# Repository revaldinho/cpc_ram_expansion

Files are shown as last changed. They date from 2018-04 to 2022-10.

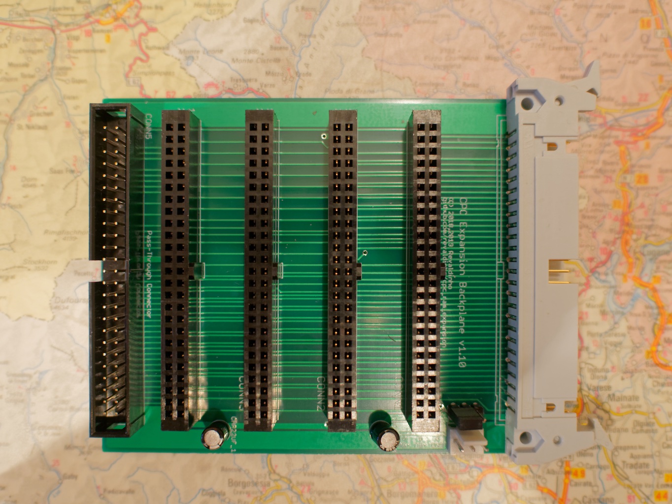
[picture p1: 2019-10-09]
img/FourSlotExpansionBoard.jpg

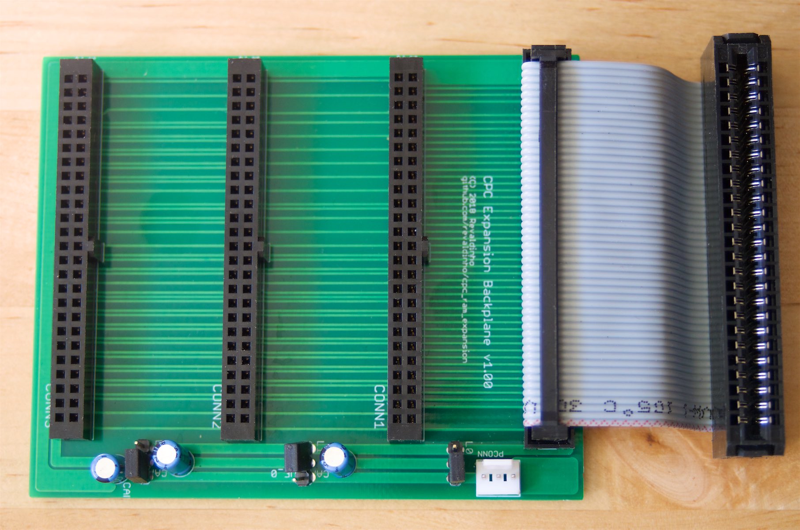
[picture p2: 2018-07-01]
img/CPC_BACKPLANE_photo.jpg

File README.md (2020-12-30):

# Amstrad CPC RAM Expansion

The main event in this GitHub project is a 1MByte RAM Expansion card for the Amstrad CPC computers from the 1980s.

In fact there are several mini-projects in here and each has its own local README file:

  * CPC RAM Expansion Cards
    * Two ['Old School'](https://github.com/revaldinho/cpc_ram_expansion/wiki/'Old-School'-CPC6128-512KB-and-1MB-RAM-Expansion-Cards) cards specifically for the 6128 and 6128 Plus and created entirely with standard 74 series ICs
      * 512KByte version
      * 1MB Version
    * [Two Universal RAM cards](https://github.com/revaldinho/cpc_ram_expansion/wiki/Universal-Amstrad-CPC-RAM-Card), compatible with all Amstrad CPC computers providing full 6128 compatibility on a 464
      * 512KByte version
      * 1MB Version
  * CPC ROM Cards
    * [CPC 4 ROM Expansion Card](https://github.com/revaldinho/cpc_ram_expansion/wiki/CPC-Fourrom-Card )
    * [CPC 6 ROM Expansion Card](https://github.com/revaldinho/cpc_ram_expansion/wiki/CPC-Sixrom-Card )
    * [CPC 8 ROM Expansion Card](https://github.com/revaldinho/cpc_ram_expansion/wiki/CPC-Eightrom-Card )
  * [CPC Expansion backplanes](https://github.com/revaldinho/cpc_ram_expansion/wiki/CPC-Expansion-Backplane)
    * 3 slot basic backplane
    * 4 slot with box connector feedthrough
    * 4 slot with replicated edge connector, allowing legacy peripherals to be daisy chained

All of the above projects have been built and tested.

Eagle PCB files and zipped archives suitable for getting boards made are included in the  [Eagle Releases](https://github.com/revaldinho/cpc_ram_expansion/blob/master/eagle_releases) subdirectory.
    
For more information on all projects see the [Project Wiki Pages](http://www.github.com/revaldinho/cpc_ram_expansion/wiki)

All programs and data files in this project are made available under the terms of the [GNU General Public License v3](https://github.com/revaldinho/cpc_ram_expansion/blob/master/LICENSE).

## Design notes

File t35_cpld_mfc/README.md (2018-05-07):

```                                 A   B
 +-------------------+              +---+
 |  PC[7:0]/DOUT[7:0]|==============|245|==**====================== Data[7:0]
 |                   |           +--|oe |  ||
 |                   |           |+-|dir|  ||
 |                   |           || +---+  ||
 | PD[15:12]/DIN[3:0]|===========||========**
 |  PB[23:16]/A[15:0]|===========||========||======*=============== A[15:8]
 |     PD[7:0]/A[7:0]|===========||========||======*=============== A[7:0]
 |                   |           || 2      ||8     | 3
 |                   |    +---------------------------------+
 |                   |    |   oeb dir    D[7:0]  A[15,14,13]|
 |        PB[0]/gpio0|-**-| gpio0[romselwr]            mreqb|------ MREQB
 |        PB[1]/gpio1|-**-| gpio1[hiromrd]            ioreqb|------ IOREQB
 |        PB[2]/gpio2|-**-| gpio2[loromrd]               wrb|------ WRB
 |        PB[3]/gpio3|-**-| gpio3                        rdb|------ RDB
 |        PB[4]/gpio4|-**-| gpio4                      romen|------ ROMEN
 |        PB[5]/gpio5|-**-| gpio5                     romdis|--|>|- ROMDIS
 |        PC[8]/gpio6|-**-| gpio6[romvalid]            waitb|------ READY
 |        PC[9]/gpio7|-**-| gpio7                        clk|------ CLK
 |                   | || |                           resetb|------ RESETB 
 |                   | || |                              m1b|------ M1B   
 |                   | || |                           busreq|------ BUSREQ
 |                   | || |                           busack|------ BUSACK
 |                   | || |                             intb|------ INT   
 |                   | || |                                 |13
 |                   | || |                             JTAG|====== JTAG TDO/TMS/TDI/TCK
 |                   | || +---------------------------------+ 4
 |       PC[10]/gpio8| || 8          
 |       PC[11]/gpio9| ++========================================== Box conn 2: 10W 
 |      PB[10]/gpio10|    
 |      PB[11]/gpio11|                                             
 |       PD[8]/gpio12|============================================= Box conn 2: 10W 
 |       PD[9]/gpio13|         
 |      PE[10]/gpio14|                                             
 |      PE[11]/gpio15|                                             
 |                   |                                         
 |      PE[24]/gpio16|                                         
 |      PE[25]/gpio17|============================================= Conn 3: 4 pin I2C 
 |                   |                                      ___
 |              DAC0 |--o pin                             o|o_o|  L1 [5V_CPC vs 5V_EXT] 
 |              DAC1 |--o pin                             _____
 +-------------------+                                    o-o o  CONN0 5V_EXT     

Questions
---------

T35 RESET access ? Separate on off (use ext supply/link) ?

Notes
-----

- USB/VIN connection needs cutting on T35 to allow use with CPC 5V in
- 3V3 supply for 9572XL parts?
  o could be second link to use T25 3V3 output [250mA]?
  o need a second link for VDD_Core pins + separate decap          
- can remove '245 and short A-B if T35 can turnaround bus quickly enough

PMOD Specs
----------

https://www.digilentinc.com/Pmods/Digilent-Pmod_%20Interface_Specification.pdf

Also check BlackIce pin out

CPLD Notes

User IO Available = 34
CPLD Tot = 8 + 2 + 8 + 3 + 13 = 34

T35 Notes

Ports Available

B[5:0], [11,10], [23:16]
C[11:0]
D[9:0], [15:11]
E[10,11,24,25,26]

SW Notes
--------

CPLD can create easier conditions to deal with e.g.

ROMSEL_WR - !A13 & !IOREQB & !WRB

HIROM_RD  - !ROMENB & A14 & ROMVALID

LOROM_RD  - !ROMENB & !A14

CPLD output signals 

ROMDIS    - !ROMENB & (ROMVALID + !A14)

OEB       - !ROMDIS

DIR       - 1'b0 - always B->A T34-> CPC in this application

Init
   ROMVALID = 0
   Tristate DOUT

On ROMSEL
   sample DATA
   save into ROMSEL
   set ROMVALID
   while ROMSEL {}

On HIROM_RD
   sample ADRHI
   sample ADRLO
   DOUT = rom[ROMSEL][ADR&0x3FFF]
   while HIROM_RD{}
   Tristate DOUT

On LOROM_RD
   sample ADRHI
   sample ADRLO
   DOUT = lorom[ADR&0x3FFF]
   while LOROM_RD{}
   Tristate DOUT
```

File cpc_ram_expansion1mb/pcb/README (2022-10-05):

#!/bin/tcsh -f
# Need to have access to the Jython netlister program
set netlister_dir = ../../../netlister
which netlister.py > /dev/null
if ($status != 0) then
   setenv CLASSPATH ${netlister_dir}/src:$CLASSPATH
   setenv PATH      ${netlister_dir}/src:$PATH
   rehash
endif

setenv TERM xterm

cp ../../common_pcb/autorouter.ctl /tmp
cp ../../common_pcb/autorouter_74.ctl /tmp
cp ../../common_pcb/design_rules.dru /tmp

## Revised CPLD based RAM board - 464 and 6128
make cpc_ram1m_plcc84.net -f ../../common_pcb/Makefile
make cpc_ram1m_plcc84.scr -f ../../common_pcb/Makefile
make cpc_ram1m_74_v2.00.net -f ../../common_pcb/Makefile
make cpc_ram1m_74_v2.00.scr -f ../../common_pcb/Makefile

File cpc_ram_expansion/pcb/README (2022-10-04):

#!/bin/tcsh -f

# Need to have access to the Jython netlister program
set netlister_dir = ~/iCloudDrive/Development/git/netlister
which netlister.py > /dev/null
if ($status != 0) then
   setenv CLASSPATH ${netlister_dir}/src:$CLASSPATH
   setenv PATH      ${netlister_dir}/src:$PATH
   rehash
endif

setenv TERM xterm

cp ../../common_pcb/design_rules.dru /tmp
cp ../../common_pcb/autorouter.ctl /tmp

## ## Original CPLD based RAM board - 6128 only
## make cpc_ram_board.net -f ../../common_pcb/Makefile
## make cpc_ram_board.scr -f ../../common_pcb/Makefile

## Revised CPLD based RAM board - 464 and 6128
make cpc_ram512k_v110.net -f ../../common_pcb/Makefile
make cpc_ram512k_v110.scr -f ../../common_pcb/Makefile

cp ../../common_pcb/design_rules.dru /tmp
cp ../../common_pcb/autorouter_74.ctl /tmp

#make cpc_ram_board_74_v2.01.scr ARGS='"-D ALT_POWER=1"' -f ../../common_pcb/Makefile
#make cpc_ram_board_74_v2.01.net ARGS='"-D ALT_POWER=1"' -f ../../common_pcb/Makefile

make cpc_ram_board_74_v3.00.scr -f ../../common_pcb/Makefile
make cpc_ram_board_74_v3.00.net -f ../../common_pcb/Makefile

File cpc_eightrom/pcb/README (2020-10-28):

#!/bin/tcsh -f

# Need to have access to the Jython netlister program

set netlister_dir = ~/Documents/nas/Development/git/netlister
which netlister.py > /dev/null
if ($status != 0) then
   setenv CLASSPATH ${netlister_dir}/src:$CLASSPATH
   setenv PATH      ${netlister_dir}/src:$PATH
   rehash
endif

setenv TERM xterm

cp ../../common_pcb/autorouter.ctl /tmp
cp ../../common_pcb/autorouter_74.ctl /tmp
cp design_rules.dru /tmp

## Revised CPLD based RAM board - 464 and 6128
make cpc_eightrom.net -f ../../common_pcb/Makefile
make cpc_eightrom.scr -f ../../common_pcb/Makefile

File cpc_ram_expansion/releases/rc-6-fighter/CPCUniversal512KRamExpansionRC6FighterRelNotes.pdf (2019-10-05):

## Summary

This is 512KByte memory expansion card which is suitable for all Amstrad CPC computers.

The card has an MX4 type connector, so requires an expansion board [1] or suitable ribbon cable connection to hook up to the computer.

On the CPC6128 and later computers the board provides a full 512K RAM expansion following the DK'Tronics/Amstrad specification.

Adding RAM to the older CPC464/664 computers is generally much more problematic than with the later models. Many of the card features are specific to these machines.

Like other RAM cards, it provides full DK'Tronics compatibility when used with the CPC464 and CPC664. This is sufficient to run the vast majority of software requiring additional RAM including CP/M Plus, demos such as Phortem and Batman Forever and many games.

The card also provides a unique 'shadow mode' which enables perfect Amstrad CPC6128 video mode C3 operation on CPC464/664 computers[2]. In shadow mode these older machines can now run FutureOS and other software relying on this video mode and which previously would run only on CPC6128s and later machines. Shadow mode can also enable a 464 to run entirely from the card RAM without using base RAM other than for the video display. This may be useful for reviving or at least diagnosing CPC464s with faulty internal RAM.

RAM Card features are controlled DIP switches which, used in combination, provide the following controls:

Overdrive ON or OFF
- select 464/664 mode (ON) or 6128/Plus mode (OFF)

•

Shadow Mode ON or OFF [464 mode only]
- ON provides 'perfect' C3 mode/ OFF provides DK'Tronics C3 mode
NB Shadow mode requires 64KB of RAM, reducing the effective capacity of the card to 448KB

○

•

Full or Partial Shadow mode [464 mode only]
Partial shadow mode uses shadow memory only for reads from remapped RAM area in mode C3

○

•

# CPC Universal 512K Ram Expansion RC-6-Fighter Release Notes

Saturday, 5 October 2019 14:17

Full shadow mode services all CPU base RAM reads from expansion card RAM
- Base RAM still used for video output via the CRTC

○

Full shadow may be useful for reviving '464s with faulty base RAM or at least diagnosing related problems but partial shadow is the default.

○

## Compatibility

The following table sets out the basic RAM card configurations required and compatibility achieved with different CPC motherboards.

| Standard Setting | | Overdrive Setting | | Overdrive/Shadow Setting
Computer | Expansion | C3 Mode | Expansion | C3 Mode | Expansion | C3 Mode
CPC464 | NA | NA | 512K | DK'T | 448K | Amstrad
CPC664 | NA | NA | 512K | DK'T | 448K | Amstrad
CPC464 [ASIC] | 512K | DK'T | NA | NA | NA | NA
CPC464 Plus | 512K | DK'T/Amstrad | NA | NA | NA | NA
CPC6128 Plus | 512K | Amstrad | NA | NA | NA | NA
KC Compact | NA | NA | 512K | DK'T | NA | NA

RAM expansion modes C0-C2 and C4-C7 work identically across all supported machines. Only the special C3 mode (requiring remapping of base memory) behaviour differs from one model to another.

On all machines the card will provide a 512KB expansion with either DK'Tronics or Amstrad C3 mode operation.

Perfect Amstrad C3 mode operation is available on all machines other than the very late CPC464 costdown revision (ASIC in place of earlier gate arrays) and the KC Compact. These machines will still get a 512KByte expansion but are limited to the DK'Tronics type C3 mode.

By default a CPC464 Plus will also get a DK'Tronics C3 mode unless a resistor is added to the motherboard. The CPC464 Plus and CPC6128Plus motherboards are identical and this resistor is an factory option component which distinguishes between the two. It is included in the CPC6128 Plus but omitted from the CPC464 Plus builds and is needed to configure the ASIC for the additional RAM banks and enable the C3 mode RAM remapping.

When using the CPC464/664 in shadow mode the effective capacity of the card is reduced by 64K to accommodate shadowing of base memory.

## DIP Switch Settings

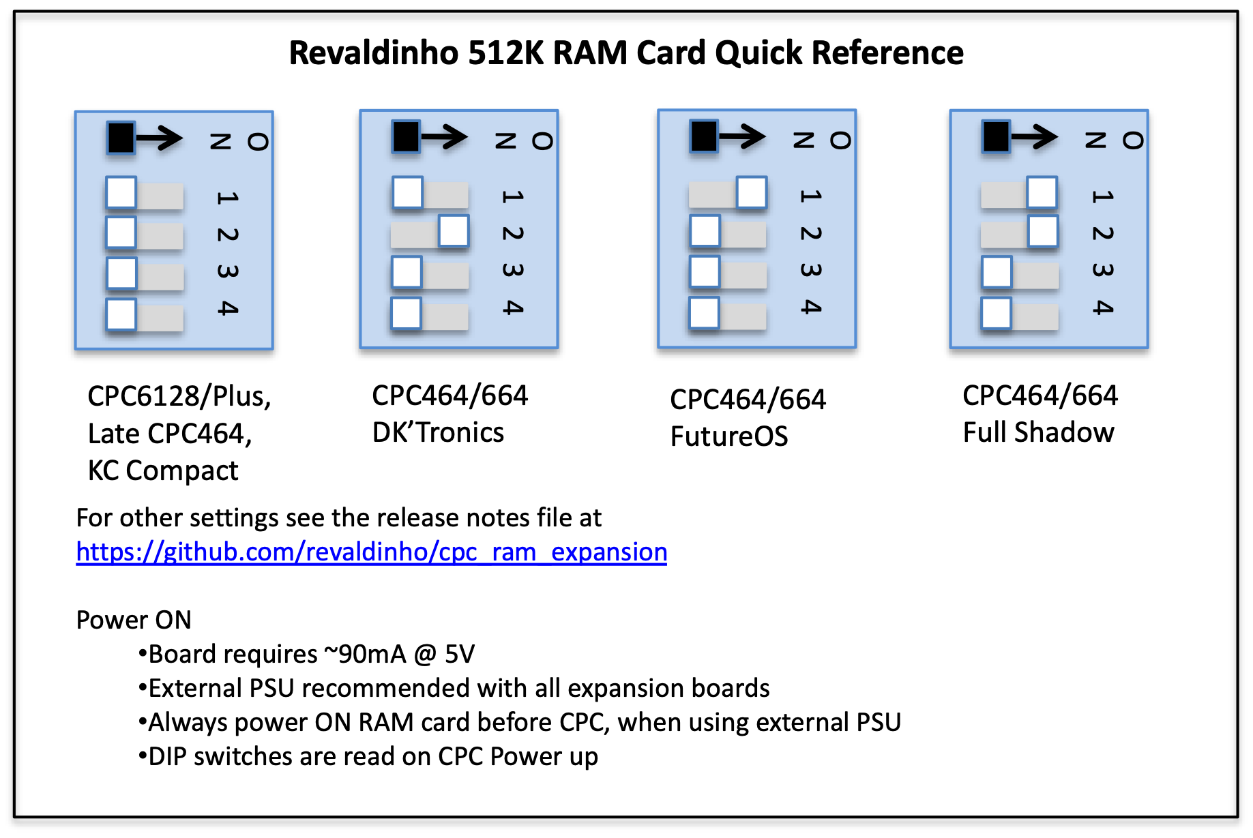
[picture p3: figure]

The new DIP settings and effects are listed below:

Config | DIP 1234 | 464/Z80 overdrive | Port | Shadow/Ban k | RAM | C3 Mode
0 | 0000 | OFF | 7Fxx | None/x | 512KB | AMSTRAD 6128
4 | 0100 | ON | 7Fxx | None/x | 512KB | DK'Tronics
8 | 1000 | ON | 7Fxx | Partial/lo | 448KB | AMSTRAD 6128
12 | 1100 | ON | 7Fxx | Full/lo | 448KB | AMSTRAD 6128

NB DIP switches 3 and 4 are not used with this firmware.

Recommended (and tested) configurations for the RAM card on its own are shown in bold in the table. E.g.

- 0 for CPC6128 providing standard 512KB expansion
- 4 for CPC464 providing 512KB expansion with DK'Tronics C3 mode
- 8 for CPC464 providing 448KB expansion with Amstrad C3 mode

Specification of other configurations is untested and may be changed in any future revisions.

## Release Notes

RC-6-Fighter is the latest firmware for the RAM card.

This release is based on RC-5-Elephant and improves low voltage operation of the card in all modes. Cards have been tested with several CPC running FutureOS and various RAM Tests and demos (including Batman and Phortem) down to around 4.1V. This should make the cards much more tolerant of poor CPC supplies and remove any need for additional external power supplies.

Unlike RC-5, the lower DIP switches are no longer used - this is because the revised logic already fills up the CPLD chip. So, the card Is now always mapped to the usual IO port &7Fxx, and doesn't have an option to relocate to &7Exx as did RC-5.

In shadow mode, the shadow bank is fixed at number 3, where previously RC-5 gave a choice of 3 or 7. Number 3 was chosen for compatibility with the DK'Tronics silicon disk software. This does an imperfect check for expansion RAM and fails to spot that the shadow bank is duplicating base RAM. So, it's not possible to use the silicon disk software with the bank set at 7 and hence the number 3 is chosen instead. The Dk'Tronics Bank manager software does correctly test for available memory and is able to find 192K (out of the maximum 256K it looks for) in banks 0,1 and 2.

## Footnotes

[1] Compatible expansion boards include ToTO's Mother X3, Revaldinho CPC Backplane, LambdaMikel LambdaBoard.
[2] When using shadow mode the card size is effectively reduced to 448KBytes
[3] Shadow mode cannot presently be used when deplying pairs of RAM cards or in conjunction with other RAM cards.
[4] The Batman Forever demo does not run on CTRC Type 2 machines

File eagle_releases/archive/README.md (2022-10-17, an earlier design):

# Eagle Releases Archive

DO NOT USE any releases in the archive area for new board builds.

All files in this area are outdated designs which have been replaced
by updated versions.

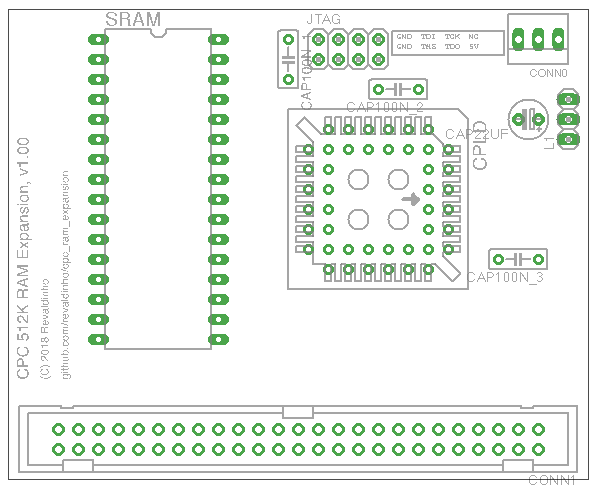
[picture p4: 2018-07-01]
img/CPC_512K_RAM_place.png

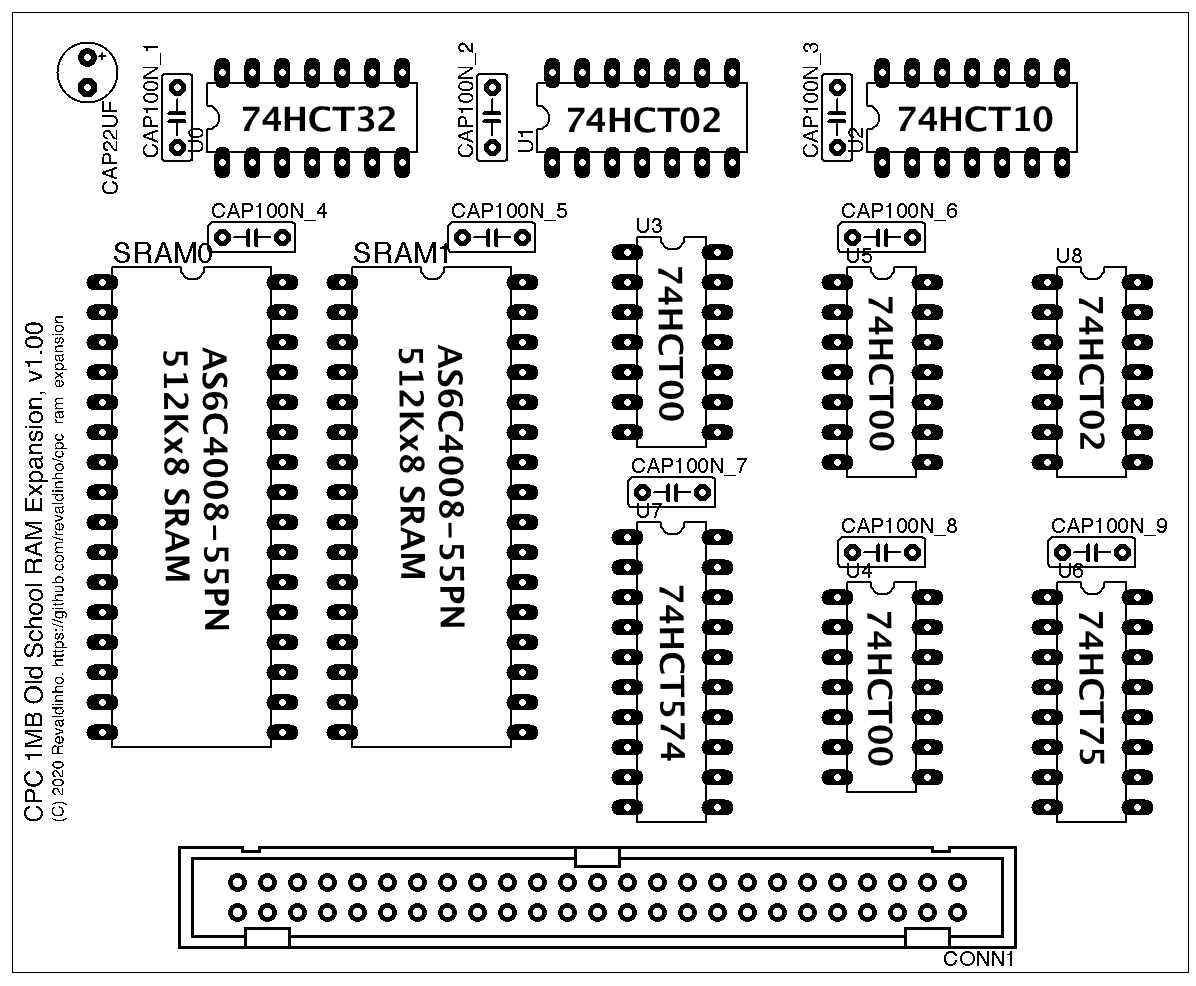
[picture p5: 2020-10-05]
img/CPC_1MB_RAM_SN74_placement_v1.00.png

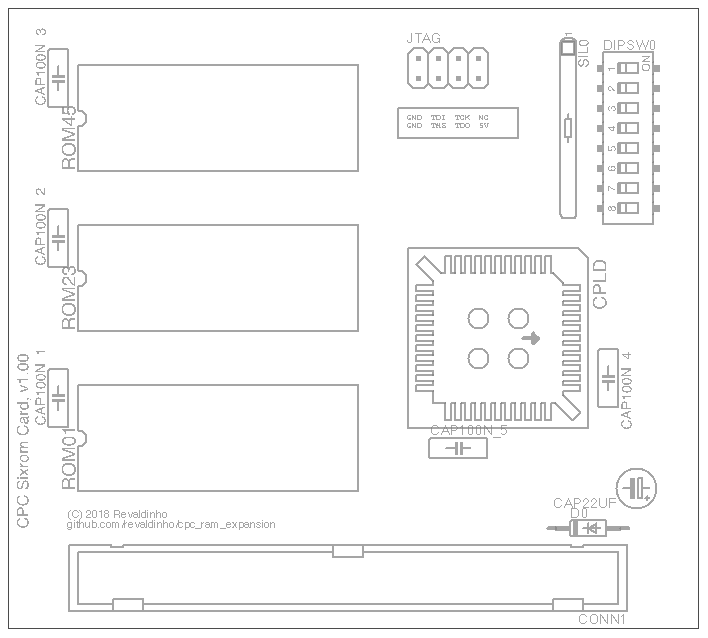
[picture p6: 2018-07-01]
img/CPC_SIXROM_place.png

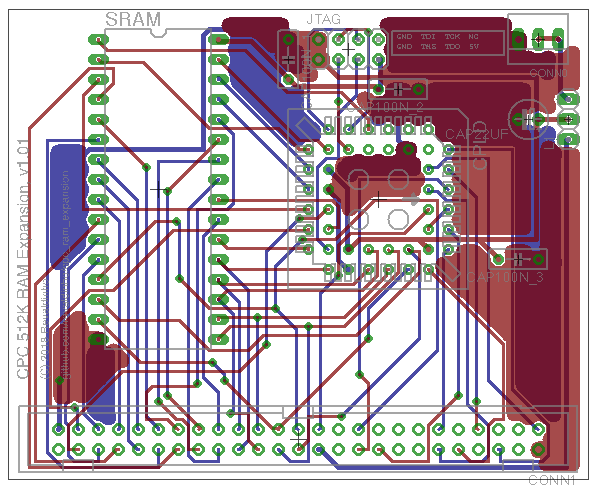
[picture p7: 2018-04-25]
img/CPC_512K_RAM_Eagle_top_v1.01.png

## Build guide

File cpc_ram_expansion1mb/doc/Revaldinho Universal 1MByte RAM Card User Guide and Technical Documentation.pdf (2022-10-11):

# Revaldinho Universal 1MByte RAM Card

# User Guide and Technical Manual

## Summary

This is a 1MByte memory expansion card which is suitable for all Amstrad CPC computers.

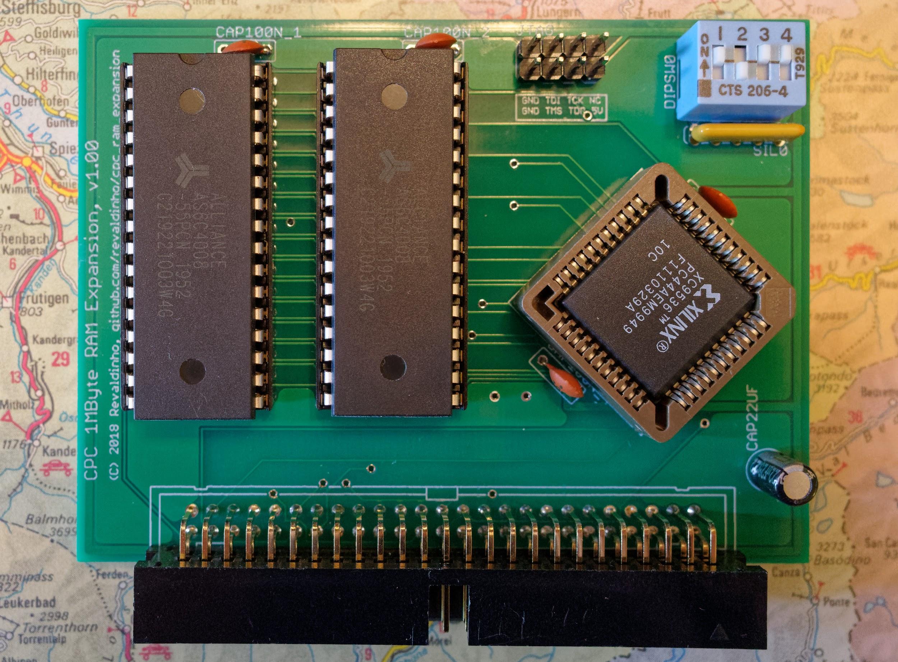
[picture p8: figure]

On all CPCs the board provides three expansion configurations
- 64KByte mode (for 464/664), to provide maximum compatibility with the CPC6128
- 512KByte mode, using Dk'Tronics expansion scheme
- 1MB mode, using the RAM7/Yarek addressing scheme.

Like other RAM cards, it provides full DK'Tronics compatibility when used with the CPC464 and CPC664 and this is sufficient to run the vast majority of software which can use the additional RAM, including CP/M Plus, demos such as Phortem and Batman Forever and many games.

The card also provides a unique 'shadow mode' which enables perfect Amstrad CPC6128 video mode C3 operation on CPC 464/664 computers. These older machines can now run FutureOS and other software which previously would run only on CPC6128s and later machines. In shadow mode the maximum expansion provided by the card is reduced to 960KBytes, as one 64KByte bank is needed to shadow the base RAM.

Shadow mode can also enable a 464 to run entirely from the card RAM without using base RAM other than for the video display. This may be useful for reviving or at least diagnosing CPC464s with faulty internal RAM.

## Table of Contents

Summary | 1
Table of Contents | 2
User Guide | 3
Installing the Card | 3
Recommended Configurations | 4
DIP Switch Settings | 4
Setting the Card Mode | 4
Setting the RAM Configuration | 6
Compatibility Tips | 7
CPC 464/664 Computers | 7
CPC 464 Plus Computers | 7
Technical Manual | 8
DK’Tronics Mode Operation | 8
Implementation and Extension of DK’Tronics Mode in the Universal Card | 10
Reduced Expansion RAM Addressing - maximum 6128 compatibility configuration. | 10
Expanded RAM Addressing - the RAM7/Yarek Scheme | 11
Shadow Mode Operation | 11
Full Shadow and Partial Shadow Modes | 12
Test Suite | 13
Validated Configurations | 14
Power Requirements | 14
Card Connector Pin-Out | 14
Downloads | 15
Additional Resources | 15
License | 15

## User Guide

### Installing the Card

The card is supplied with an MX4 type connector rather than an edge connector, so requires an expansion board or ribbon cable connection to hook up to the computer. All modern expansion boards have the same pin-out which mimics IDC connectors on a ribbon cable. The RAM card connector is keyed, to ensure that it will fit only in the correct orientation in a matching socket, such as the ones installed in the Revaldinho CPC Expansion Boards. Some other expansion boards use cheaper non-keyed connections which make it possible to insert the card the wrong way round. For those boards, take care to insert the card so that the component side of the board (including the DIP switch) is facing the rear of the Amstrad CPC computer.

The card draws approximately 100mA of current when running with a 5V supply. This should be handled by a standard CPC power supply and although cards are tested down to 4.5V to allow for some voltage drop over old edge connectors, it’s a good idea to clean the connectors on your CPC to minimize this. If your expansion board allows an external power supply to be used, then it’s recommended to connect one, particularly if you are using a number of different peripherals as well as the RAM card.

Once the card is physically installed, it’s necessary to configure it appropriately before switching on the computer. This is done by setting the 4 DIP switches on the top level of the circuit board.

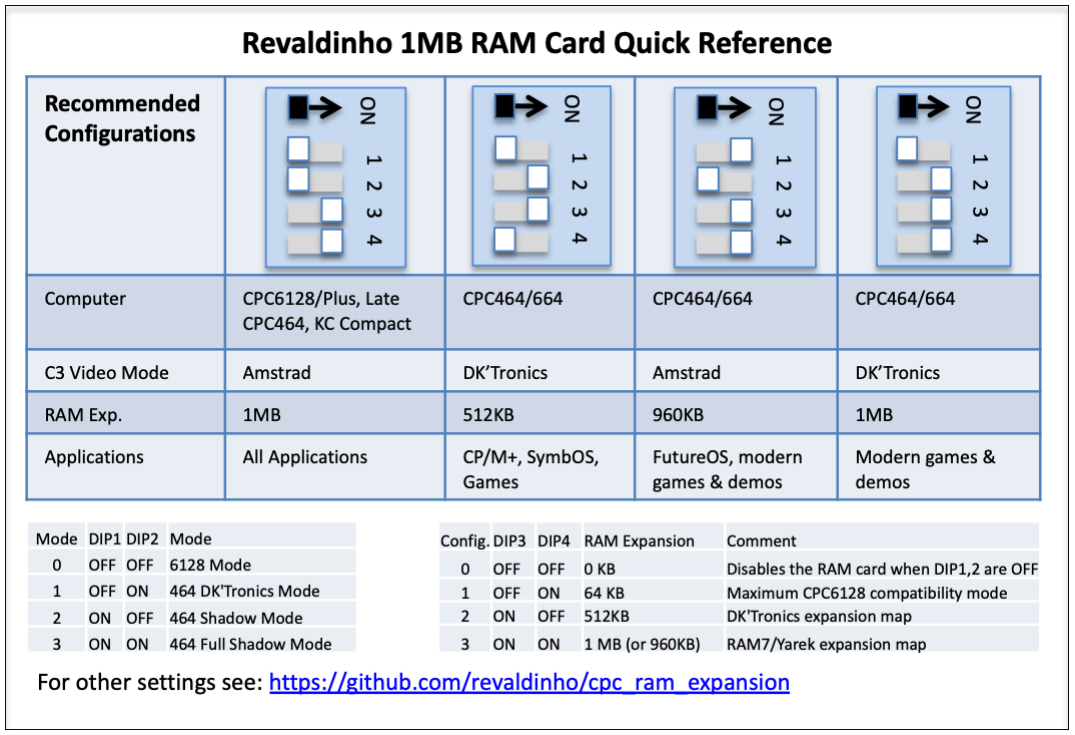
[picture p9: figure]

### Recommended Configurations

Computer | DIP1 | DIP2 | DIP3 | DIP4 | Expansion | Application
CPC 6128/Plus | OFF | OFF | ON | ON | 1MB | All
CPC 464/664 | ON | OFF | ON | ON | 960KB | FutureOS
CPC 464/664 | OFF | ON | OFF | ON | 64KB | CPC 6128 games 1
CPC 464/664 | OFF | ON | ON | OFF | 512KB | CP/M+ , SymbOS, DK’Tronics silicon disk 2
CPC 464/664 | OFF | ON | ON | ON | 1MB | Modern games & demos
All | OFF | OFF | OFF | OFF | None | Disable the card

The table above shows the most common DIP settings needed for different CPC models and software. Other settings are possible and described in more detail below.

### DIP Switch Settings

The board has four DIP switches which are grouped into two pairs
- DIP1 and DIP2 determine the card mode
- DIP3 and DIP4 determine the RAM expansion size

Changing DIP settings while the computer is running is likely to cause a crash, but even if it doesn't you should always reset the computer after a change.

### Setting the Card Mode

The card has 4 operating modes shown in the table below.

Mode | DIP1 | DIP2 | Mode | C3 Video | Comment
0 | OFF | OFF | 6128 Mode | Amstrad | Always use this mode for CPC6128 & Plus computers 3
1 | OFF | ON | DK'Tronics Mode | DK'Tronics | Basic DK'Tronics compatible expansion for CPC464/664
2 | ON | OFF | Shadow Mode | Amstrad | Enhanced mode expansion with perfect Amstrad C3
3 | ON | ON | Full Shadow Mode | Amstrad | Enhanced mode expansion with perfect Amstrad C3

For CPC 6128, CPC Plus and late ‘cost reduced’ CPC 464

3 models, always select mode 0.

The other modes are all intended for the vast majority of older CPC 464 and 664 computers. These computers do not handle expanded memory as cleanly as the CPC 6128, so the RAM card needs to overdrive some of the key CPU signals at critical moments to write-protect the CPC’s internal memory and

3 Use this mode also for very late model CPC 464 computers which have the very small motherboard and ASIC in place of the original gate array ICs.

2 See Compatibility Tips for CPC 464/664 Computers

1 May also require the CPC 6128 upper BASIC and lower Firmware ROMs to be installed.

to remap some of that memory in one specific configuration. Modes 1-3 are the only modes suitable for CPC 464/664 computers, and all implement the electrical overdrive operation.

The main difference between modes 1-3 is the way in which the C3 video mode is handled. There is a choice between DK'Tronics handling of the C3 video mode and true CPC 6128-type handling. Most software is perfectly happy with the DK'Tronics implementation. Mode 1 implements this and is good for running CP/M+ using the DK'Tronics software to provide a 256KByte RAM disk for example.

Some software needs a perfect implementation of the Amstrad C3 mode and FutureOS is perhaps the best example of this. To be able to run this software chose either mode 2 or mode 3. There is no obvious difference to the user between these two modes. In both modes 2 and 3 all CPU writes to base memory are also sent to the shadow bank in the expansion board. Mode 3 disables all CPU reads from base RAM and replaces them with read data from the expansion board, whereas mode 2 does this only for reads from the upper 16KB of base memory. Both schemes provide the perfect C3 mode operation.

Since mode 3 replaces all CPU reads from base RAM with data from the expansion board, it’s possible that using this mode could revive a CPC 464/664 with faulty base RAM. If the faulty RAM is in the video address space, then unfortunately there will still be a corrupted screen display because it’s not possible for the expansion board to service reads to the CRTC chip. Even so, in theory at least, it would be possible to boot and run a CPC 464/664 in this way which might at least help with fault diagnosis.

### Setting the RAM Configuration

As well as the operating modes, there are four possible RAM configurations described in the table below.

Config. | DIP3 | DIP4 | RAM Expansion | Comment
0 | OFF | OFF | 0 KB | Effectively disables the RAM card
1 | OFF | ON | 64 KB | Maximum CPC6128 compatibility mode
2 | ON | OFF | 512KB | DK'Tronics expansion
3 | ON | ON | 1 MB (or 960KB) | RAM7/Yarek expansion

In configuration 0, the RAM card is completely disabled. There may be rare cases where a CPC 464/664 needs to run in an unexpanded RAM mode, but you shouldn’t normally need to select this mode.

Configuration 1 is provided to give CPC 464/664s maximum compatibility with the CPC 6128. In this mode all expanded memory accesses are mapped to the same 64KByte expansion bank. This configuration can be used with both DK’Tronics and Amstrad C3 video modes (above) with no effect on the size of the expansion.

Configuration 2 models a ‘standard’ DK’Tronics 512KByte expansion scheme. DK’Tronics sold several different expansion cards back in the 80s including a 64KByte RAM expansion, a 256KByte expansion and a 256KByte silicon disk. All of these conformed to this scheme and the RAM expansion and silicon disk could be used together for a total of 512KBytes. In configuration 2, the card replicates this scheme exactly and the original DK’Tronics RAM expansion (bank management) and silicon disk software work without modification. This configuration can be used in conjunction with both DK’Tronics and Amstrad C3 video modes without affecting the size of expansion RAM available.

Configuration 3 provides the maximum memory expansion. This uses the RAM7/Yarek scheme which extends the DK’Tronics standard. Most legacy software able to access expanded RAM will be able to run in this mode even if it doesn’t access the full 1MByte. Only more modern software will make full use of this mode, but that does include the operating system FutureOS as well as a number of demos. On a CPC 464/664, FutureOS will need one of the two shadow modes 2 or 3 to be selected in conjunction with this configuration because it specifically needs the full Amstrad C3 video operation; other software will be ok with any of modes 1-3. When one of the shadow modes is selected, the maximum RAM expansion available in this configuration is reduced to 960KBytes because one 64K bank is needed to shadow the CPC’s base memory.

Note that in all cases the total RAM of the CPC is the internal 64K base memory + the additional RAM Expansion. So in 512KB mode for example, the CPC actually has 576KBytes of RAM. This is true for all machines including the CPC 6128 and Plus because the built-in 64KByte expansion in these machines is disabled when an additional RAM card is added.

### Compatibility Tips

CPC 464/664 Computers

To upgrade a CPC 464/664 computer to full CPC 6128 specification you will need to add a memory expansion card but also change both the BASIC and lower Firmware ROMs. Some games check for the ROM types to determine the machine type or RAM size for example.

Even with the CPC 6128 ROMs installed, you may find some software won’t run due to other subtle hardware differences including the keyboard scanning arrangement. DK’Tronics recognized this and provided a set of RSXes as a workaround as part of their RAM expansion software. In particular the |EMULATE command deals with differences in the keyboard map. On some CPC 464s you must install and run the RSX before you can boot into CP/M+ for example (otherwise it returns a message to the effect “CP/M+ does not support this environment”).

For most legacy CPC software, running in DK’Tronics compatibility mode (mode 1) and either 512K or 64K RAM configurations is recommended because older software wasn’t written to target the Yarek/RAM7 addressing scheme.

Note that although SymbOS claims to be Yarek/RAM7 compatible, it only recognizes 512KB of expansion on the 1MB card irrespective of whether the 512KB or 1MB memory setting is selected. Other more recent software is likely to be able to use the full 1MByte mode.

See the compatibility and testing table later for more specific software information.

CPC Plus Computers

When CPC464 and CPC6128 Plus computers are running software which makes use of advanced features new to these machines compared with the older CPC family, there are some restrictions on compatibility. Specifically, any software which remaps the ASIC register bank into RAM space (at 0x4000-0x7FFF0 must first disable the expansion RAM before performing the remapping. With the ASIC registers mapped in this space there is a clash with the expansion RAM if this is not done - all writes go to both ASIC and expansion memory; all reads come from ASIC and expansion RAM too, causing a clash on the databus.

CPC 464 Plus Computers

The CPC 464 Plus and CPC 6128 Plus share the same ASIC and motherboard, but there are differences in components fitted to the two boards. Obviously the CPC464 Plus is missing the additional 64KByte RAM bank of the CPC 6128 Plus, but less obviously this affects the way in which expansion RAM is handled in the video mode C3.

The CPC 464 Plus should always use the RAM card mode 0 (non-overdrive mode) but by default the C3 video mode will behave as it would on an older CPC 464 with a DK’Tronics expansion. However, it is possible to update the CPC 464 Plus to inherit the same clean RAM expansion handling as the CPC 6128 and by adding a single component. On page 18 of the Service Manual , “Gate Array / Output Interface

4

4 The Amstrad CPC Plus Service Manual can be found here: http://www.cpcwiki.eu/manuals/Service%20Manual%20Amstrad%20Plus.zip

Schematic Diagram” you will see a note at the bottom of the page to the effect that resistor R128 (10Kohm) needs to be added for the board to recognize an on-board 64K expansion (ie 128K rather than 64K). Adding this resistor will also update the RAM handling to that of the CPC 6128, and the 1MByte RAM card will do the rest. In this way the CPC 464 Plus can gain the full 1MB expansion and run FutureOS and other C3 mode dependent software.

## Technical Manual

The following sections describe in more detail the various RAM expansion schemes and how the card implements different compatibility modes.

### DK’Tronics Mode Operation

The board is fully compatible with the DK'Tronics/Amstrad bank switching schemes described in the DK'Tronics Peripheral Technical Manual. (http://www.cpcwiki.eu/imgs/8/83/DK%27Tronics_Peripheral_-_Technical_Manual_%28Edition_1%29.pdf)

In this scheme there are 8 possible 64K banks, and each bank is split into 4 16K blocks.
Selecting a 64K bank is done by writing to the Z80 IO address 0x7Fxx with an 8 bit dataword.
Bit position | 7 | 6 | 5 | 4 | 3 | 2 | 1 | 0
Value | 0 | 1 | c | c | c | b | b | b

The two MSBs of the byte must be set to 01 and then the rest of the byte is divided into two 3 bit fields:
- ccc - picks one of 8 possible 64K banks
- bbb - selects a block switching scheme within the chosen bank

In true DK’Tronics mode operation, the maximum RAM expansion size is limited to 512KBytes.

Within any one 64KByte bank, RAM is divided up into 4 16KByte blocks numbered from 0 (the lowest 16KBytes) to 3 (the highest 16KBytes).

The bank switching schemes for the 6128 and Plus machines are illustrated in the table below, where
- '-' indicates access to internal RAM
- 0-3 indicate access to the relevant block in the selected external expansion bank

| Block Scheme (bbb)
Address | 000 | 001 | 010 | 011 | 100 | 101 | 110 | 011
0xC000-0xFFFF | - | 3 | 3 | 3 | - | - | - | -
0x8000-0xBFFF | - | - | 2 | - | - | - | - | -
0x4000-0x7FFF | - | - | 1 | ** | 0 | 1 | 2 | 3
0x0000-0x3FFF | - | - | 0 | - | - | - | - | -

Bank 0 would normally select the single internal 64K expansion bank in a 6128, but when the card is attached this bank is disabled and the first bank in the external expansion is accessed instead.

In the special case '**' marked in column '011' internal memory at 0x4000-0x7FFF is remapped to 0xC000-0xFFFF. This is the special ‘C3’ mode referred to in the user guide, and is handled internally in the CPC 6128 and Plus machines, but not in the CPC 464/664.

Whenever expansion RAM is accessed, the card asserts the ‘RAMDIS’ signal on the CPC’s edge connector. On the CPC 6128 this is sufficient to disable all read and write access to internal base RAM. However, on the CPC 464/664 this signal disables only internal memory reads - i.e. all writes to expansion RAM will also go to internal base memory, thereby corrupting it. Much of the complexity in all CPC 464/664 RAM expansion cards goes into dealing with this situation.

DK-Tronics expansions and other modern reimplementations deal with this problem by backdriving the A15 and MREQ* signals coming out of the CPU.

On all expansion RAM writes the cards detect a memory request and then quickly overdrive MREQ* fast enough that the gate array does not initiate an internal memory access. This effectively write-protects the internal RAM when accessing expansion memory.

Overdriving the A15 signal is used in mode C3 to do the internal remapping. When these cards detect an access to internal RAM block 1 in C3 mode, the A15 signal is overdriven to ‘1’ to turn it into an access to internal RAM block 3 instead. This works very well for write operations to internal memory, and this is sufficient to run software which uses this mode only to write to video memory.

Unfortunately, this does not work for software which uses this mode to remap CPU read accesses from (internal RAM) block 1 to block 3. This is due to the way in which the CPC handles ROM and RAM accesses. If the upper ROM is disabled when one a read access is made, then all is well - the RAM address will be remapped and the RAM data from the uppermost block will be returned correctly to the CPU. However, if upper ROM is enabled when a read access is made then the gate array will assume that ROM data is required and return ROM rather than RAM data. This prevents standard DK’Tronics cards or re-implementations performing a perfect C3 mode emulation, and hence these cards are unable to run FutureOS and other software which is dependent on that.

### Implementation and Extension of DK’Tronics Mode in the Universal Card

For maximum compatibility with older software this card provides modes which will operate exactly as described above. Under the hood, there are some slight differences in the way the electrical back-driving is done.

Firstly the card chooses to overdrive the RD* signal rather than the MREQ* signal to write-protect base RAM. The RD* signal is interpreted as ‘write not read’ by the CPC’s gate array IC. When a write to expansion RAM is detected the card forces RD* low so that the gate array instead thinks a read is being performed. The gate array will still initiate an internal RAM access but now it’s a non-destructive read and the card’s assertion of the RAMDIS signal means that the internal RAM data never makes it to the CPU bus.

Overdriving RD* was chosen for electrical reasons. When the signal is overdriven there is an electrical conflict between the CPU and the CPLD on the expansion card. With TTL logic it’s easier to win a conflict by driving to ‘0’ rather than ‘1’.

There is no alternative to overdriving A15 to ‘1’ (in conflict with the CPU driving it to ‘0’) in C3 mode. To provide some more robust operation here the CPLD gangs two output pins together to drive this particular signal.

In this way full DK'Tronics compatibility is provided on all models of Amstrad Computer including the CPC464 and 664. This mode of operation still suffers from the same C3 mode limitations as the original of course. The solution to this is the shadow mode described later.

Reduced Expansion RAM Addressing - maximum 6128 compatibility configuration.

In a standard Amstrad CPC6128, there is 64K of base RAM and only a single 64K expansion bank. Selection of that RAM bank is still done by writing a byte to the Z80 IO address 0x7Fxx.

Bit position | 7 | 6 | 5 | 4 | 3 | 2 | 1 | 0
Value | 0 | 1 | X | X | X | b | b | b

In this case bits 3-5 are ignored: all accesses to expansion RAM are sent to the only available 64K expansion bank. The 3 LSBs are still used to select the block access mode.

The card provides an option to limit the RAM expansion to 64KBytes for any legacy software which assumes this reduced addressing scheme. This provides maximum CPC 6128 compatibility when expanding a CPC 464/664.

### Expanded RAM Addressing - the RAM7/Yarek Scheme

The Amstrad/DK’Tronics bank addressing scheme only allows 8 64KByte banks to be selected, limiting RAM expansions to a maximum of 512KBytes.

The RAM7/Yarek scheme expands this by more strictly controlling the Z80 IO port addressing used to select expansion RAM.

In the original scheme, writes to the Z80 IO port 0x7Fxx selects the expansion RAM bank & block mode.

In the RAM7/Yarek scheme the range of IO port addresses 0x7Exx - 0x7Fxx are used to select expansion RAM banks, with the second highest nybble of the IO port address being interpreted as additional RAM bank selection bits.

This 1 MByte card provides 16 banks of 64KBytes each.

- Banks 0-7 are accessed by writing the RAM configuration register at Z80 IO address 0x7Fxx.
- Banks 8-15 are accessed by writing the RAM configuration register at Z80 IO address 0x7Exx.

### Shadow Mode Operation

Shadow mode operation applies only to CPC 464/664 computers.

The previous sections have described the various RAM addressing options and DK’Tronics emulation of the C3 video mode and its limitations in running some software, most notably FutureOS. This section describes in more detail the unique shadow mode which finally enables a perfect C3 video mode to be implemented on the CPC 464/664 and for software which requires it to run on these machines where previously they were confined to the CPC 6128 and later models.

In shadow mode, the card keeps an exact copy of the CPC’s base RAM contents in a single bank of the expansion RAM: whenever the CPC writes to base memory the card copies that transaction also into the chosen bank in the expansion RAM. Block 7 is chosen as the shadow bank, leaving blocks 8-15 free to operate normally in the 64KByte and 512KByte RAM expansion modes for maximum compatibility. When running in 1MByte mode, block 7 is not available as an expansion RAM block and any reads or writes to this block are aliased to Block 6 instead. This is detected by modern OSes and identified as a 64KByte ‘hole’ in the 1MByte map, reducing the maximum capacity of the card to 960KBytes.

When the CPC is running in the video C3 mode, all writes to block 1 of internal RAM are remapped to block 3 by overdriving the A15 bit to ‘1’, exactly as the DK’Tronics hardware would. At the same time these writes are copied also to block 3 of the shadow bank on the expansion card.

The key difference between shadow mode and DK’tronics mode is for the read operations. On DK’Tronics cards remapping block 1 reads to block 3 is not reliable because the data returned depends on whether upper ROM is enabled or not. Frequently ROM data is returned instead of the required RAM data and this causes, for example, corruption of the screen pointer in the FutureOS GUI. It may also cause crashes in other software.

Since the expansion RAM is keeping a perfect copy of the internal RAM data in shadow RAM, it no longer needs to do any overdriving of the A15 signal for read operations. Instead, when a C3 read from block 1 is detected the card disables internal memory by asserting RAMDIS and returns the data from block 3 (i.e. the remapped address space) in the expansion card shadow bank instead. In this way the gate array doesn’t see A15 high during the read and does not attempt to enable any of the ROMs.

Shadow mode provides perfect Amstrad CPC 6128 C3 mode emulation for older CPC 464/664 computers and is the only way to run C3 dependent software on these machines.

### Full Shadow and Partial Shadow Modes

The card offers two versions of the shadow mode.

In partial shadow mode, all writes to base memory are copied to the shadow bank but only CPU reads from block 1 (addresses 0x4000-0x7FFF) are taken from the shadow bank.

In full shadow mode, again all writes to base memory are copied to the shadow bank but this time the shadow bank is used to service all CPU reads from base memory. The RAMDIS signal is asserted for all memory reads while in full shadow mode, disabling CPU reads from base memory completely.

Both modes have been tested across a range of voltage on a small number of CPC 464 machines with no discernable difference in reliability between them. These tests have included specific RAM tests (DK’Tronics, Duke’s RAM512KB test, the FutureOS RAM test program and so on) as well as running various OSes, demos and games. In full shadow mode, the card passes the tests in Gerald’s test ROM which is often seen as the best test of base memory.

It’s not practical to replicate all CPC environments though, as the ‘464 went through a number of motherboard revisions, three gate array/asic types (in two different technologies) and was built with Z80, CRTC and RAM components from a number of different manufacturers over its production lifetime. Additionally these machines are now 30 years old and some will have aged better than others. Since there are subtle differences in timing between the two shadow modes, you may find that one works better than the other with a particular CPC 464/664.

When running in full shadow mode, the CPC’s internal RAM is only used by the CRTC chip to drive the video display. This means that it’s possible that an old CPC with faulty internal RAM can be revived by using this mode. If the RAM problems are in an area access by the video controller then of course there will still be corruption on screen, but the rest of memory for program execution should work perfectly so it should at least be possible to boot and run the system which will either make it usable or help in diagnosing the exact RAM issue.

### Test Suite

In developing the card the hardware has been tested across a voltage range of 4.25V to 5.5V using the following test suite running on a CPC 6128 and a CPC 464 (high key model).

- RAM Test Software
- Duke’s RAM512KB test (tests only 512KB RAM)
- FutureOS RAM test (tests full 1MB)
- ERAM-TST (tests full 1MB(
- TEST.BIN (tests only 512KB RAM)
- RAMTEST.BIN/RAMTEST.BAS (included in the GitHub distribution, detects full 1MB RAM)
- Gerald’s RAM Test ROM (Full shadow mode only for test of base RAM)
- OS and Applications Software
- CP/M+ (Runs only in DK’Tronics mode on a CPC464)

5
■ with BBC BASIC and Borland TurboPascal
- FutureOS with the Gianna Sisters game (Shadow modes only) and demos
- SymbOS GUI (NB. SymbOS recognizes only 512KB on the card)
- DK’Tronics Silicon Disk
- DK’Tronics RAM Expansion RSXes
- Games
- Chase HQ

6
- Double Dragon
- Gryzor
- Hard Drivin’
- Prehistorik II
- R-Type

7
- Robocop
- ZapTBall (Runs only in DK’Tronics mode on a CPC464)

7
- Demos
- Batman Forever

8
- Phortem

Any cards sold as built and tested by Revaldinho are run through the RAM tests and a subset of the rest of the test suite at a fixed 4.5V voltage on a CPC 464, checking all the main board operating modes.

8 Not compatible with all CRTC types - this is not a RAM/Firmware issue

7 Requires the CPC 6128 lower and upper ROMs to be installed

6 Not compatible with FutureOS ROMs - disable or remove these before running

5 Booting CP/M+ requires use of the DK’Tronics |EMULATE RSX first on a CPC 464

### Validated Configurations

The following computer configurations have been verified using the previous generation 512KByte card, on which this 1MB version is based.

| Mode 0 | Mode 1 | Modes 2 & 3
Computer | Expansion | C3 Mode | Expansion | C3 Mode | Expansion | C3 Mode
CPC 464 | NA | NA | 512K | DK'T | 448K | Amstrad
CPC 664 | NA | NA | 512K | DK'T | 448K | Amstrad
CPC 464 [ASIC] | 512K | DK'T | NA | NA | NA | NA
CPC 464 Plus | 512K | DK'T/ Amstrad 9 | NA | NA | NA | NA
CPC 6128 Plus | 512K | Amstrad | NA | NA | NA | NA
KC Compact | NA | NA | 512K | DK'T | NA | NA

### Power Requirements

At 5V the card draws approximately 100mA from the power supply.

### Card Connector Pin-Out

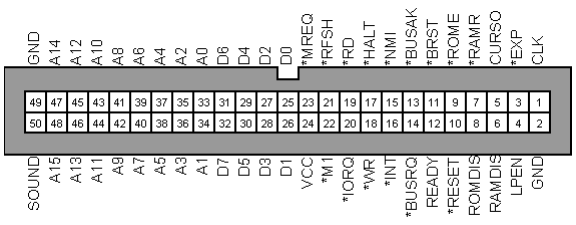
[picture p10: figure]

Pins on the card connector are numbered as shown above, looking into the pins of the connector.

This is the standard arrangement for modern expansion boards, including the open-source Revaldinho boards, Mother X4 and LambdaBoards - see the CPC-WIKI for more details.

9 Refer to the CPC Plus section in the Compatibility Tips above

### Downloads

Some of the key software mentioned in the text above can be downloaded from the web.

- DK’Tronics Silicon Disk and RAM expansion RSXes
- http://www.cpcwiki.eu/index.php/Dk%27tronics_memory_expansion
- Duke’s 512KB Test (testing DK’T and Amstrad C3 modes)
- https://github.com/M4Duke/z80
- FutureOS Homepage
- http://futureos.cpc-live.com
- SymbOS Homepage
- http://www.symbos.org
- Richard Russell’s Z80 BBC BASIC Page
- http://www.bbcbasic.co.uk/bbcbasic/z80basic.html
- Gerald’s CPC base RAM Test
- http://www.cpcwiki.eu/forum/amstrad-cpc-hardware/quick-and-dirty-ram-test-for-cpc/

### Additional Resources

All source code and further documentation for this card and other related CPC projects are made available on Github: https://github.com/revaldinho/cpc_ram_expansion

## License

All programs and data files in this project are made available under the terms of the GNU General Public License v3. (https://github.com/revaldinho/cpc_ram_expansion/blob/master/LICENSE)

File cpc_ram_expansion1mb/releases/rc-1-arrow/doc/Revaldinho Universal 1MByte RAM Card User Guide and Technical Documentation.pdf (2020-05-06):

# Revaldinho Universal 1MByte RAM Card

# User Guide and Technical Manual

## Summary

This is a 1MByte memory expansion card which is suitable for all Amstrad CPC computers.

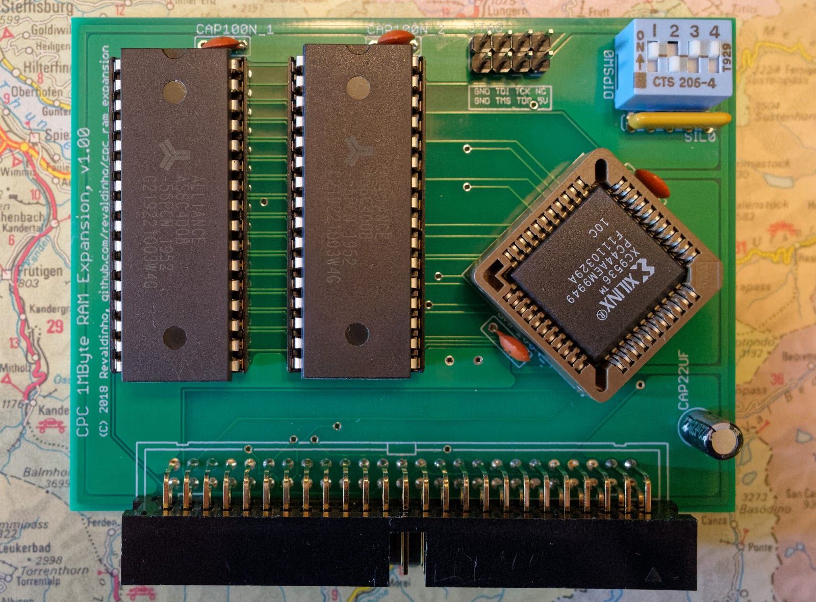
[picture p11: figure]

On all CPCs the board provides three expansion configurations
- 64KByte mode (for 464/664), to provide maximum compatibility with the CPC6128
- 512KByte mode, using Dk'Tronics expansion scheme
- 1MB mode, using the RAM7/Yarek addressing scheme.

Like other RAM cards, it provides full DK'Tronics compatibility when used with the CPC464 and CPC664 and this is sufficient to run the vast majority of software which can use the additional RAM, including CP/M Plus, demos such as Phortem and Batman Forever and many games.

The card also provides a unique 'shadow mode' which enables perfect Amstrad CPC6128 video mode C3 operation on CPC 464/664 computers. These older machines can now run FutureOS and other software which previously would run only on CPC6128s and later machines. In shadow mode the maximum expansion provided by the card is reduced to 960KBytes, as one 64KByte bank is needed to shadow the base RAM.

Shadow mode can also enable a 464 to run entirely from the card RAM without using base RAM other than for the video display. This may be useful for reviving or at least diagnosing CPC464s with faulty internal RAM.

## Table of Contents

Revaldinho Universal 1MByte RAM Card | 1
User Guide and Technical Manual | 1
Summary | 1
Table of Contents | 2
User Guide | 3
Installing the Card | 3
Recommended Configurations | 3
DIP Switch Settings | 3
Setting the Card Mode | 4
Setting the RAM Configuration | 5
Compatibility Tips | 6
CPC 464/664 Computers | 6
CPC 464 Plus Computers | 6
Technical Manual | 7
DK’Tronics Mode Operation | 7
Implementation and Extension of DK’Tronics Mode in the Universal Card | 9
Reduced Expansion RAM Addressing - maximum 6128 compatibility configuration. | 9
Expanded RAM Addressing - the RAM7/Yarek Scheme | 10
Shadow Mode Operation | 10
Full Shadow and Partial Shadow Modes | 11
Test Suite | 12
Validated Configurations | 13
Power Requirements | 13
Card Connector Pin-Out | 13
Downloads | 14
Additional Resources | 14
License | 14

## User Guide

### Installing the Card

The card is supplied with an MX4 type connector rather than an edge connector, so requires an expansion board or ribbon cable connection to hook up to the computer. All modern expansion boards have the same pin-out which mimics IDC connectors on a ribbon cable. The RAM card connector is keyed, to ensure that it will fit only in the correct orientation in a matching socket, such as the ones installed in the Revaldinho CPC Expansion Boards. Some other expansion boards use cheaper non-keyed connections which make it possible to insert the card the wrong way round. For those boards, take care to insert the card so that the component side of the board (including the DIP switch) is facing the rear of the Amstrad CPC computer.

The card draws approximately 100mA of current when running with a 5V supply. This should be handled by a standard CPC power supply and although cards are tested down to 4.5V to allow for some voltage drop over old edge connectors, it’s a good idea to clean the connectors on your CPC to minimize this. If your expansion board allows an external power supply to be used, then it’s recommended to connect one, particularly if you are using a number of different peripherals as well as the RAM card.

Once the card is physically installed, it’s necessary to configure it appropriately before switching on the computer. This is done by setting the 4 DIP switches on the top level of the circuit board.

### Recommended Configurations

Computer | DIP1 | DIP2 | DIP3 | DIP4 | Expansion | Application
CPC 6128/Plus | OFF | OFF | ON | ON | 1MB | All
CPC 464/664 | ON | OFF | ON | ON | 960KB | FutureOS
CPC 464/664 | OFF | ON | OFF | ON | 64KB | CPC 6128 games 1
CPC 464/664 | OFF | ON | ON | OFF | 512KB | CP/M+ , DK’Tronics silicon disk 2
CPC 464/664 | OFF | ON | ON | ON | 1MB | SymbOS

The table above shows the most common DIP settings needed for different CPC models and software. Other settings are possible and described in more detail below.

### DIP Switch Settings

The board has four DIP switches which are grouped into two pairs
- DIP1 and DIP2 determine the card mode
- DIP3 and DIP4 determine the RAM expansion size

Changing DIP settings while the computer is running is likely to cause a crash, but even if it doesn't you should always reset the computer after a change.

1 May also require the CPC 6128 upper BASIC and lower Firmware ROMs to be installed.
2 See Compatibility Tips for CPC 464/664 Computers

### Setting the Card Mode

The card has 4 operating modes shown in the table below.

Mode | DIP1 | DIP2 | Mode | C3 Video | Comment
0 | OFF | OFF | 6128 Mode | Amstrad | Always use this mode for CPC6128 & Plus computers 3
1 | OFF | ON | DK'Tronics Mode | DK'Tronics | Basic DK'Tronics compatible expansion for CPC464/664
2 | ON | OFF | Shadow Mode | Amstrad | Enhanced mode expansion with perfect Amstrad C3
3 | ON | ON | Full Shadow Mode | Amstrad | Enhanced mode expansion with perfect Amstrad C3

For CPC 6128, CPC Plus and late ‘cost reduced’ CPC 464

3 models, always select mode 0.

The other modes are all intended for the vast majority of older CPC 464 and 664 computers. These computers do not handle expanded memory as cleanly as the CPC 6128, so the RAM card needs to overdrive some of the key CPU signals at critical moments to write-protect the CPC’s internal memory and to remap some of that memory in one specific configuration. Modes 1-3 are the only modes suitable for CPC 464/664 computers, and all implement the electrical overdrive operation.

The main difference between modes 1-3 is the way in which the C3 video mode is handled. There is a choice between DK'Tronics handling of the C3 video mode and true CPC 6128-type handling. Most software is perfectly happy with the DK'Tronics implementation. Mode 1 implements this and is good for running CP/M+ using the DK'Tronics software to provide a 256KByte RAM disk for example.

Some software needs a perfect implementation of the Amstrad C3 mode and FutureOS is perhaps the best example of this. To be able to run this software chose either mode 2 or mode 3. There is no obvious difference to the user between these two modes. In both modes 2 and 3 all CPU writes to base memory are also sent to the shadow bank in the expansion board. Mode 3 disables all CPU reads from base RAM and replaces them with read data from the expansion board, whereas mode 2 does this only for reads from the upper 16KB of base memory. Both schemes provide the perfect C3 mode operation.

Since mode 3 replaces all CPU reads from base RAM with data from the expansion board, it’s possible that using this mode could revive a CPC 464/664 with faulty base RAM. If the faulty RAM is in the video address space, then unfortunately there will still be a corrupted screen display because it’s not possible for the expansion board to service reads to the CRTC chip. Even so, in theory at least, it would be possible to boot and run a CPC 464/664 in this way which might at least help with fault diagnosis.

3 Use this mode also for very late model CPC 464 computers which have the very small motherboard and ASIC in place of the original gate array ICs.

### Setting the RAM Configuration

As well as the operating modes, there are four possible RAM configurations described in the table below.

Config. | DIP3 | DIP4 | RAM Expansion | Comment
0 | OFF | OFF | 0 KB | Effectively disables the RAM card
1 | OFF | ON | 64 KB | Maximum CPC6128 compatibility mode
2 | ON | OFF | 512KB | DK'Tronics expansion
3 | ON | ON | 1 MB (or 960KB) | RAM7/Yarek expansion

In configuration 0, the RAM card is completely disabled. There may be rare cases where a CPC 464/664 needs to run in an unexpanded RAM mode, but you shouldn’t normally need to select this mode.

Configuration 1 is provided to give CPC 464/664s maximum compatibility with the CPC 6128. In this mode all expanded memory accesses are mapped to the same 64KByte expansion bank. This configuration can be used with both DK’Tronics and Amstrad C3 video modes (above) with no effect on the size of the expansion.

Configuration 2 models a ‘standard’ DK’Tronics 512KByte expansion scheme. DK’Tronics sold several different expansion cards back in the 80s including a 64KByte RAM expansion, a 256KByte expansion and a 256KByte silicon disk. All of these conformed to this scheme and the RAM expansion and silicon disk could be used together for a total of 512KBytes. In configuration 2, the card replicates this scheme exactly and the original DK’Tronics RAM expansion (bank management) and silicon disk software work without modification. This configuration can be used in conjunction with both DK’Tronics and Amstrad C3 video modes without affecting the size of expansion RAM available.

Configuration 3 provides the maximum memory expansion. This uses the RAM7/Yarek scheme which extends the DK’Tronics standard. Most legacy software able to access expanded RAM will be able to run in this mode even if it doesn’t access the full 1MByte. Only more modern software will make full use of this mode, but that does include the operating systems SymbOS and FutureOS as well as a number of demos. On a CPC 464/664, FutureOS will need one of the two shadow modes 2 or 3 to be selected in conjunction with this configuration because it specifically needs the full Amstrad C3 video operation; other software will be ok with any of modes 1-3. When one of the shadow modes is selected, the maximum RAM expansion available in this configuration is reduced to 960KBytes because one 64K bank is needed to shadow the CPC’s base memory.

Note that in all cases the total RAM of the CPC is the internal 64K base memory + the additional RAM Expansion. So in 512KB mode for example, the CPC actually has 576KBytes of RAM. This is true for all machines including the CPC 6128 and Plus because the built-in 64KByte expansion in these machines is disabled when an additional RAM card is added.

### Compatibility Tips

CPC 464/664 Computers

To upgrade a CPC 464/664 computer to full CPC 6128 specification you will need to add a memory expansion card but also change both the BASIC and lower Firmware ROMs. Some games check for the ROM types to determine the machine type or RAM size for example.

Even with the CPC 6128 ROMs installed, you may find some software won’t run due to other subtle hardware differences including the keyboard scanning arrangement. DK’Tronics recognized this and provided a set of RSXes as a workaround as part of their RAM expansion software. In particular the |EMULATE command deals with differences in the keyboard map. On some CPC 464s you must install and run the RSX before you can boot into CP/M+ for example (otherwise it returns a message to the effect “CP/M+ does not support this environment”).

For most legacy CPC software, running in DK’Tronics compatibility mode (mode 1) and either 512K or 64K RAM configurations is recommended because older software wasn’t written to target the Yarek/RAM7 addressing scheme.

More recent software is likely to be able to use the full 1MByte mode.

CPC 464 Plus Computers

The CPC 464 Plus and CPC 6128 Plus share the same ASIC and motherboard, but there are differences in components fitted to the two boards. Obviously the CPC464 Plus is missing the additional 64KByte RAM bank of the CPC 6128 Plus, but less obviously this affects the way in which expansion RAM is handled in the video mode C3.

The CPC 464 Plus should always use the RAM card mode 0 (non-overdrive mode) but by default the C3 video mode will behave as it would on an older CPC 464 with a DK’Tronics expansion. However, it is possible to update the CPC 464 Plus to inherit the same clean RAM expansion handling as the CPC 6128 and by adding a single component. On page 18 of the Service Manual , “Gate Array / Output Interface

4
Schematic Diagram” you will see a note at the bottom of the page to the effect that resistor R128 (10Kohm) needs to be added for the board to recognize an on-board 64K expansion (ie 128K rather than 64K). Adding this resistor will also update the RAM handling to that of the CPC 6128, and the 1MByte RAM card will do the rest. In this way the CPC 464 Plus can gain the full 1MB expansion and run FutureOS and other C3 mode dependent software.

4 The Amstrad CPC Plus Service Manual can be found here: http://www.cpcwiki.eu/manuals/Service%20Manual%20Amstrad%20Plus.zip

## Technical Manual

The following sections describe in more detail the various RAM expansion schemes and how the card implements different compatibility modes.

### DK’Tronics Mode Operation

The board is fully compatible with the DK'Tronics/Amstrad bank switching schemes described in the DK'Tronics Peripheral Technical Manual. (http://www.cpcwiki.eu/imgs/8/83/DK%27Tronics_Peripheral_-_Technical_Manual_%28Edition_1%29.pdf)

In this scheme there are 8 possible 64K banks, and each bank is split into 4 16K blocks.
Selecting a 64K bank is done by writing to the Z80 IO address 0x7Fxx with an 8 bit dataword.
Bit position | 7 | 6 | 5 | 4 | 3 | 2 | 1 | 0
Value | 0 | 1 | c | c | c | b | b | b

The two MSBs of the byte must be set to 01 and then the rest of the byte is divided into two 3 bit fields:
- ccc - picks one of 8 possible 64K banks
- bbb - selects a block switching scheme within the chosen bank

In true DK’Tronics mode operation, the maximum RAM expansion size is limited to 512KBytes.

Within any one 64KByte bank, RAM is divided up into 4 16KByte blocks numbered from 0 (the lowest 16KBytes) to 3 (the highest 16KBytes).

The bank switching schemes for the 6128 and Plus machines are illustrated in the table below, where
- '-' indicates access to internal RAM
- 0-3 indicate access to the relevant block in the selected external expansion bank

| Block Scheme (bbb)
Address | 000 | 001 | 010 | 011 | 100 | 101 | 110 | 011
0xC000-0xFFFF | - | 3 | 3 | 3 | - | - | - | -
0x8000-0xBFFF | - | - | 2 | - | - | - | - | -
0x4000-0x7FFF | - | - | 1 | ** | 0 | 1 | 2 | 3
0x0000-0x3FFF | - | - | 0 | - | - | - | - | -

Bank 0 would normally select the single internal 64K expansion bank in a 6128, but when the card is attached this bank is disabled and the first bank in the external expansion is accessed instead.

In the special case '**' marked in column '011' internal memory at 0x4000-0x7FFF is remapped to 0xC000-0xFFFF. This is the special ‘C3’ mode referred to in the user guide, and is handled internally in the CPC 6128 and Plus machines, but not in the CPC 464/664.

Whenever expansion RAM is accessed, the card asserts the ‘RAMDIS’ signal on the CPC’s edge connector. On the CPC 6128 this is sufficient to disable all read and write access to internal base RAM. However, on the CPC 464/664 this signal disables only internal memory reads - i.e. all writes to expansion RAM will also go to internal base memory, thereby corrupting it. Much of the complexity in all CPC 464/664 RAM expansion cards goes into dealing with this situation.

DK-Tronics expansions and other modern reimplementations deal with this problem by backdriving the A15 and MREQ* signals coming out of the CPU.

On all expansion RAM writes the cards detect a memory request and then quickly overdrive MREQ* fast enough that the gate array does not initiate an internal memory access. This effectively write-protects the internal RAM when accessing expansion memory.

Overdriving the A15 signal is used in mode C3 to do the internal remapping. When these cards detect an access to internal RAM block 1 in C3 mode, the A15 signal is overdriven to ‘1’ to turn it into an access to internal RAM block 3 instead. This works very well for write operations to internal memory, and this is sufficient to run software which uses this mode only to write to video memory.

Unfortunately, this does not work for software which uses this mode to remap CPU read accesses from (internal RAM) block 1 to block 3. This is due to the way in which the CPC handles ROM and RAM accesses. If the upper ROM is disabled when one a read access is made, then all is well - the RAM address will be remapped and the RAM data from the uppermost block will be returned correctly to the CPU. However, if upper ROM is enabled when a read access is made then the gate array will assume that ROM data is required and return ROM rather than RAM data. This prevents standard DK’Tronics cards or re-implementations performing a perfect C3 mode emulation, and hence these cards are unable to run FutureOS and other software which is dependent on that.

### Implementation and Extension of DK’Tronics Mode in the Universal Card

For maximum compatibility with older software this card provides modes which will operate exactly as described above. Under the hood, there are some slight differences in the way the electrical back-driving is done.

Firstly the card chooses to overdrive the RD* signal rather than the MREQ* signal to write-protect base RAM. The RD* signal is interpreted as ‘write not read’ by the CPC’s gate array IC. When a write to expansion RAM is detected the card forces RD* low so that the gate array instead thinks a read is being performed. The gate array will still initiate an internal RAM access but now it’s a non-destructive read and the card’s assertion of the RAMDIS signal means that the internal RAM data never makes it to the CPU bus.

Overdriving RD* was chosen for electrical reasons. When the signal is overdriven there is an electrical conflict between the CPU and the CPLD on the expansion card. With TTL logic it’s easier to win a conflict by driving to ‘0’ rather than ‘1’.

There is no alternative to overdriving A15 to ‘1’ (in conflict with the CPU driving it to ‘0’) in C3 mode. To provide some more robust operation here the CPLD gangs two output pins together to drive this particular signal.

In this way full DK'Tronics compatibility is provided on all models of Amstrad Computer including the CPC464 and 664. This mode of operation still suffers from the same C3 mode limitations as the original of course. The solution to this is the shadow mode described later.

Reduced Expansion RAM Addressing - maximum 6128 compatibility configuration.

In a standard Amstrad CPC6128, there is 64K of base RAM and only a single 64K expansion bank. Selection of that RAM bank is still done by writing a byte to the Z80 IO address 0x7Fxx.

Bit position | 7 | 6 | 5 | 4 | 3 | 2 | 1 | 0
Value | 0 | 1 | X | X | X | b | b | b

In this case bits 3-5 are ignored: all accesses to expansion RAM are sent to the only available 64K expansion bank. The 3 LSBs are still used to select the block access mode.

The card provides an option to limit the RAM expansion to 64KBytes for any legacy software which assumes this reduced addressing scheme. This provides maximum CPC 6128 compatibility when expanding a CPC 464/664.

### Expanded RAM Addressing - the RAM7/Yarek Scheme

The Amstrad/DK’Tronics bank addressing scheme only allows 8 64KByte banks to be selected, limiting RAM expansions to a maximum of 512KBytes.

The RAM7/Yarek scheme expands this by more strictly controlling the Z80 IO port addressing used to select expansion RAM.

In the original scheme, writes to the Z80 IO port 0x7Fxx selects the expansion RAM bank & block mode.

In the RAM7/Yarek scheme the range of IO port addresses 0x7FF0 - 0x7FFF are used to select expansion RAM banks, with the 4 LSBs of the IO port address being interpreted as additional RAM bank selection bits.

This 1 MByte card provides 16 banks of 64KBytes each.

- Banks 0-7 are accessed by writing the RAM configuration register at Z80 IO address 0x7FFE.
- Banks 8-15 are accessed by writing the RAM configuration register at Z80 IO address 0x7FFF.

### Shadow Mode Operation

Shadow mode operation applies only to CPC 464/664 computers.

The previous sections have described the various RAM addressing options and DK’Tronics emulation of the C3 video mode and its limitations in running some software, most notably FutureOS. This section describes in more detail the unique shadow mode which finally enables a perfect C3 video mode to be implemented on the CPC 464/664 and for software which requires it to run on these machines where previously they were confined to the CPC 6128 and later models.

In shadow mode, the card keeps an exact copy of the CPC’s base RAM contents in a single bank of the expansion RAM: whenever the CPC writes to base memory the card copies that transaction also into the chosen bank in the expansion RAM. Block 7 is chosen as the shadow bank, leaving blocks 8-15 free to operate normally in the 64KByte and 512KByte RAM expansion modes for maximum compatibility. When running in 1MByte mode, block 7 is not available as an expansion RAM block and any reads or writes to this block are aliased to Block 6 instead. This is detected by modern OSes and identified as a 64KByte ‘hole’ in the 1MByte map, reducing the maximum capacity of the card to 960KBytes.

When the CPC is running in the video C3 mode, all writes to block 1 of internal RAM are remapped to block 3 by overdriving the A15 bit to ‘1’, exactly as the DK’Tronics hardware would. At the same time these writes are copied also to block 3 of the shadow bank on the expansion card.

The key difference between shadow mode and DK’tronics mode is for the read operations. On DK’Tronics cards remapping block 1 reads to block 3 is not reliable because the data returned depends on whether upper ROM is enabled or not. Frequently ROM data is returned instead of the required RAM data and this causes, for example, corruption of the screen pointer in the FutureOS GUI. It may also cause crashes in other software.

Since the expansion RAM is keeping a perfect copy of the internal RAM data in shadow RAM, it no longer needs to do any overdriving of the A15 signal for read operations. Instead, when a C3 read from block 1 is detected the card disables internal memory by asserting RAMDIS and returns the data from block 3 (i.e. the remapped address space) in the expansion card shadow bank instead. In this way the gate array doesn’t see A15 high during the read and does not attempt to enable any of the ROMs.

Shadow mode provides perfect Amstrad CPC 6128 C3 mode emulation for older CPC 464/664 computers and is the only way to run C3 dependent software on these machines.

### Full Shadow and Partial Shadow Modes

The card offers two versions of the shadow mode.

In partial shadow mode, all writes to base memory are copied to the shadow bank but only CPU reads from block 1 (addresses 0x4000-0x7FFF) are taken from the shadow bank.

In full shadow mode, again all writes to base memory are copied to the shadow bank but this time the shadow bank is used to service all CPU reads from base memory. The RAMDIS signal is permanently asserted while in full shadow mode, disabling CPU reads from base memory completely.

Both modes have been tested across a range of voltage on a small number of CPC 464 machines with no discernable difference in reliability between them. These tests have included specific RAM tests (DK’Tronics, Duke’s RAM512KB test, the FutureOS RAM test program and so on) as well as running various OSes, demos and games. In full shadow mode, the card passes the tests in Gerald’s test ROM which is often seen as the best test of base memory.

It’s not practical to replicate all CPC environments though, as the ‘464 went through a number of motherboard revisions, three gate array/asic types (in two different technologies) and was built with Z80, CRTC and RAM components from a number of different manufacturers over its production lifetime. Additionally these machines are now 30 years old and some will have aged better than others. Since there are subtle differences in timing between the two shadow modes, you may find that one works better than the other with a particular CPC 464/664.

When running in full shadow mode, the CPC’s internal RAM is only used by the CRTC chip to drive the video display. This means that it’s possible that an old CPC with faulty internal RAM can be revived by using this mode. If the RAM problems are in an area access by the video controller then of course there will still be corruption on screen, but the rest of memory for program execution should work perfectly so it should at least be possible to boot and run the system which will either make it usable or help in diagnosing the exact RAM issue.

### Test Suite

In developing the card the hardware has been tested across a voltage range of 4.25V to 5.5V using the following test suite running on a CPC 6128 and a CPC 464 (high key model).

- RAM Test Software
- Duke’s RAM512KB test
- FutureOS RAM test
- TEST.BIN
- RAMTEST.BIN/RAMTEST.BAS (included in the GitHub distribution)
- Gerald’s RAM Test ROM (Full shadow mode only)
- OS and Applications Software
- CP/M+ with BBC BASIC and Borland TurboPascal

5
- FutureOS with the Gianna Sisters game (shadow modes only)
- DK’Tronics Silicon Disk
- DK’Tronics RAM Expansion RSXes
- Games
- Chase HQ

6
- Double Dragon
- Gryzor
- Hard Drivin’
- Prehistorik II
- R-Type

7
- Robocop
- ZapTBall

7
- Demos
- Batman Forever

8
- Phortem

Any cards sold as built and tested by Revaldinho are run through the RAM tests and a subset of the rest of the test suite at a fixed 4.5V voltage on a CPC 464, checking all the main board operating modes.

5 Booting CP/M+ requires use of the DK’Tronics |EMULATE RSX first on a CPC 464 6 Not compatible with FutureOS ROMs - disable or remove these before running
7 Requires the CPC 6128 lower and upper ROMs to be installed
8 Not compatible with all CRTC types - this is not a RAM/Firmware issue

### Validated Configurations

The following computer configurations have been verified using the previous generation 512KByte card, on which this 1MB version is based.

| Mode 0 | Mode 1 | Modes 2 & 3
Computer | Expansion | C3 Mode | Expansion | C3 Mode | Expansion | C3 Mode
CPC 464 | NA | NA | 512K | DK'T | 448K | Amstrad
CPC 664 | NA | NA | 512K | DK'T | 448K | Amstrad
CPC 464 [ASIC] | 512K | DK'T | NA | NA | NA | NA
CPC 464 Plus | 512K | DK'T/ Amstrad 9 | NA | NA | NA | NA
CPC 6128 Plus | 512K | Amstrad | NA | NA | NA | NA
KC Compact | NA | NA | 512K | DK'T | NA | NA

### Power Requirements

At 5V the card draws approximately 100mA from the power supply.

### Card Connector Pin-Out

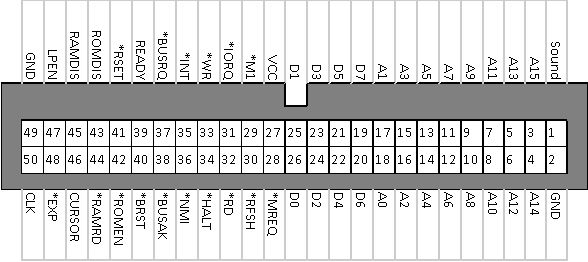
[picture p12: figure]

Pins on the card connector are numbered as shown above, looking into the pins of the connector.

This is the standard arrangement for most popular modern expansion boards, including the open-source Revaldinho boards, Mother X4 and LambdaBoards - see the CPC-WIKI for more details.

9 Refer to the CPC Plus section in the Compatibility Tips above

### Downloads

Some of the key software mentioned in the text above can be downloaded from the web.

- DK’Tronics Silicon Disk and RAM expansion RSXes
- http://www.cpcwiki.eu/index.php/Dk%27tronics_memory_expansion
- Duke’s 512KB Test (testing DK’T and Amstrad C3 modes)
- https://github.com/M4Duke/z80
- FutureOS Homepage
- http://futureos.cpc-live.com
- SymbOS Homepage
- http://www.symbos.org
- Richard Russell’s Z80 BBC BASIC Page
- http://www.bbcbasic.co.uk/bbcbasic/z80basic.html
- Gerald’s CPC base RAM Test
- http://www.cpcwiki.eu/forum/amstrad-cpc-hardware/quick-and-dirty-ram-test-for-cpc/

### Additional Resources

All source code and further documentation for this card and other related CPC projects are made available on Github: https://github.com/revaldinho/cpc_ram_expansion

## License

All programs and data files in this project are made available under the terms of the GNU General Public License v3. (https://github.com/revaldinho/cpc_ram_expansion/blob/master/LICENSE)

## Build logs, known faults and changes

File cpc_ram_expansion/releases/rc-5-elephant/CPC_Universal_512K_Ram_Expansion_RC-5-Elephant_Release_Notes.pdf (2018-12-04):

## Summary

This is 512KByte memory expansion card which is suitable for all Amstrad CPC computers.

The card has an MX4 type connector, so requires an expansion board [1] or suitable ribbon cable connection to hook up to the computer.

On the CPC6128 and later computers the board provides a full 512K RAM expansion following the DK'Tronics/Amstrad specification.

Adding RAM to the older CPC464/664 computers is generally much more problematic than with the later models. Many of the card features are specific to these machines.

Like other RAM cards, it provides full DK'Tronics compatibility when used with the CPC464 and CPC664. This is sufficient to run the vast majority of software requiring additional RAM including CP/M Plus, demos such as Phortem and Batman Forever and many games.

The card also provides a unique 'shadow mode' which enables perfect Amstrad CPC6128 video mode C3 operation on CPC464/664 computers[2]. In shadow mode these older machines can now run FutureOS and other software relying on this video mode and which previously would run only on CPC6128s and later machines. Shadow mode can also enable a 464 to run entirely from the card RAM without using base RAM other than for the video display. This may be useful for reviving or at least diagnosing CPC464s with faulty internal RAM.

RAM Card features are controlled by a bank of 4 DIP switches which, used in combination, provide the following controls:

Overdrive ON or OFF
- select 464/664 mode (ON) or 6128/Plus mode (OFF)

•

IO Port HIGH/LOW
- maps Memory either to IO port &7Fxx (HIGH) or &7Exx (LOW)
- allows two cards to work together to provide up to 1MB of RAM

•

Shadow Mode ON or OFF [464 mode only]
- ON provides 'perfect' C3 mode/ OFF provides DK'Tronics C3 mode
NB Shadow mode requires 64KB of RAM, reducing the effective capacity of the card to 448KB

○

•

Full or Partial Shadow mode [464 mode only]

•

## CPC Universal 512K Ram Expansion RC-5-Elephant Release Notes

Friday, 16 November 2018 21:46

Full or Partial Shadow mode [464 mode only]
Partial shadow mode uses shadow memory only for reads from remapped RAM area in mode C3

○

Full shadow mode services all CPU base RAM reads from expansion card RAM
- Base RAM still used for video output via the CRTC

○

Full shadow may be useful for reviving '464s with faulty base RAM or at least diagnosing related problems but partial shadow is the default.

○

•

Shadow bank HIGH or LOW [464 mode only]
- Maps shadow bank to either Bank 3 (low) or Bank 7 (high)
- Use Low if using DK'T silicon disk which doesn't do a good check for available RAM
- Use High - more generally to have contiguous banks 0-6 available rather than 0-2,4-7

•

## Compatibility

The following table sets out the basic RAM card configurations required and compatibility achieved with different CPC motherboards.

| Standard Setting | | Overdrive Setting | | Overdrive/Shadow Setting
Computer | Expansion | C3 Mode | Expansion | C3 Mode | Expansion | C3 Mode
CPC464 | NA | NA | 512K | DK'T | 448K | Amstrad
CPC664 | NA | NA | 512K | DK'T | 448K | Amstrad
CPC464 [ASIC] | 512K | DK'T | NA | NA | NA | NA
CPC464 Plus | 512K | DK'T/Amstrad | NA | NA | NA | NA
CPC6128 Plus | 512K | Amstrad | NA | NA | NA | NA
KC Compact | NA | NA | 512K | DK'T | NA | NA

RAM expansion modes C0-C2 and C4-C7 work identically across all supported machines. Only the special C3 mode (requiring remapping of base memory) behaviour differs from one model to another.

On all machines the card will provide a 512KB expansion with either DK'Tronics or Amstrad C3 mode operation.

Perfect Amstrad C3 mode operation is available on all machines other than the very late CPC464 costdown revision (ASIC in place of earlier gate arrays) and the KC Compact. These machines will still get a 512KByte expansion but are limited to the DK'Tronics type C3 mode.

By default a CPC464 Plus will also get a DK'Tronics C3 mode unless a resistor is added to the motherboard. The CPC464 Plus and CPC6128Plus motherboards are identical and this resistor is an factory option component which distinguishes between the two. It is included in the CPC6128 Plus but omitted from the CPC464 Plus builds and is needed to configure the ASIC for the additional RAM banks and enable the C3 mode RAM remapping.

When using the CPC464/664 in shadow mode the effective capacity of the card is reduced by 64K to accommodate shadowing of base memory.

## DIP Switch Settings

The new DIP settings and effects are listed below:

Config | DIP 1234 | 464/Z80 overdrive | Port | Shadow/ Bank | RAM | C3 Mode
0 | 0000 | OFF | 7Fxx | None/x | 512KB | AMS
1 | 0001 | OFF | 7Fxx | None/x | 512KB | AMS
2 | 0010 | OFF | 7Exx | None/x | 512KB | AMS
3 | 0011 | OFF | 7Exx | None/x | 512KB | AMS
4 | 0100 | ON | 7Fxx | None/x | 512KB | DK'T
5 | 0101 | ON | 7Fxx | None/x | 512KB | DK'T
6 | 0110 | ON | 7Exx | None/x | 512KB | DK'T
7 | 0111 | ON | 7Exx | None/x | 512KB | DK'T
8 | 1000 | ON | 7Fxx | Partial/lo | 448KB | AMS
9 | 1001 | ON | 7Fxx | Partial/hi | 448KB | AMS
10 | 1010 | ON | 7Exx | Partial/lo | 448KB | AMS
11 | 1011 | ON | 7Exx | Partial/hi | 448KB | AMS
12 | 1100 | ON | 7Fxx | Full/lo | 448KB | AMS
13 | 1101 | ON | 7Fxx | Full/hi | 448KB | AMS
14 | 1110 | ON | 7Exx | Full/lo | 448KB | AMS
15 | 1111 | ON | 7Exx | Full/hi | 448KB | AMS

NB DIP switches 3 and 4 are only read on powering up the CPC. If you use an external supply for the RAM card be sure to switch that on before the main CPC supply.

Recommended (and tested) configurations for the RAM card on its own are shown in bold in the table. E.g.

- 0 for CPC6128 providing standard 512KB expansion
- 4 for CPC464 providing 512KB expansion with DK'Tronics C3 mode
- 8 for CPC464 providing 448KB expansion with Amstrad C3 mode

Specification of other configurations is untested and may be changed in any future revisions.

## Using the RAM card in pairs or with X-MEM/Y-MEM

Two RAM cards can be used together to provide up to 1MByte of expansion on all CPCs. On a CPC6128 it's also possible to use one RAM card together with an X-MEM or Y-MEM to get 1MByte of RAM expansion.

To use two RAM cards together to get a 1MB expansion, one card must be set up to map memory to IO Port &7Fxx and the other to IO Port &7E00.

On a 6128 or later machine the following combinations of cards will all provide 1 MByte of RAM expansion

Slot 1 | IO Port | Config | Slot 2 | IO Port | Config | Expansion Size | Comment
RAM | &7exx | 0010 | RAM | &7fxx | 0000 | 1MByte
Y-MEM | &7exx | - | RAM | &7fxx | 0000 | 1MByte
RAM | &7exx | 0010 | X-MEM | &7fxx | - | 1MByte

It's not recommended to mix X-MEM/Y-MEM and the RAM card on a 464 due to the different ways with which these cards deal with the Z80 signal backdriving. Also, on a 464/664 when using two RAM cards together there are some restrictions due to the potential for clashing of overdrive signals when mixing modes. However, it is still possible to get either full 1MByte RAM expansion with DK'Tronics C3 mode, or a 960KByte expansion with perfect Amstrad C3 mode (e.g. for FutureOS) using one of these two settings as appropriate:

Slot 1 Config (IO Port) | Slot 2 Config (IO Port) | Expansion | C3 Mode | Comment
0110 (&7exx) | 0000 (&7Fxx) | 1MByte | DK'Tronics | Card in slot1 does all overdriving
1010 (&7exx) | 0000 (&7Fxx) | 960KByte | Amstrad | Card in Slot 1 does all overdriving and provides shadow RAM

## Release Notes

RC-5-Elephant is a beta test candidate.

This release is based on RC-4-Dolphin, but fixes an incompatibility with the M4 multi-function card which prevented the latter being used as a ROM board.

The problem was found to be in two parts and related to the unusual tactic of the RAM card in driving the RD_B line low to write protect CPC464 base memory when writing to external RAM, rather than the more usual driving of MREQ_B high.

The first issue occurs at the start of the write cycle. The low going edge on the overdriven RD_B signal triggers the M4's interrupt mechanism and the M4 then inspects only IORQ_B and WR_B to determine if a ROM access is occurring. The M4 keeps track internally of whether and which ROMs are enabled, so doesn't query the ROMEN_B line from the gate array for each access. So, although the RD_B pulse doesn't cause a new ROMEN_B to be issued by the gate array, the M4 can still interpret this as a ROM read. When this happens the M4 drives the databus with ROM data at the same time the CPU is writing to external RAM. The fix for this is for the RAM card to blip WR_B low simultaneously with the low going RD_B and hold it low for just the high phase of the clock. This is enough to invalidate the M4 ROM access check. The WR_B signal does not go to the gate array, which instead uses only RD_B as a writeNotRead type signal. So for all RAM accesses on the main board the WR_B signal is a don't care.

The second issue occurs at the end of a memory write cycle. At this point the RAM card is still driving RD_B low, but it is possible for this signal to glitch when the address bus changes. Again, the gate array and hardware ROM cards are unaffected by a glitch on RD_B but the M4 interrupt can be triggered by the low going glitch on RD_B. At this time WR_B and IORQ_B are usually both high and so again the M4 can attempt to drive the databus as if a ROM access were occurring. The fix for this is to prevent the glitch and this has been done by latching the signal which indicates an expansion RAM access inside the CPLD.

Other changes in this update are related to use of the card in pairs or with X-Mem/Y-Mem on a 6128.

Using IO Port &7Exx is no longer disabled when the card in is shadow mode, but care needs to be taken picking suitable modes for pairs of cards as described above.

Overdriving signals are no longer disabled when the card is currently not selected. Again, take care in picking suitable modes for pairs of cards but this change allows one card to operate in overdrive mode and provide shadow memory while the other is run in '6128' mode and so provide the maximum of 960KB expansion and still have the perfect Amstrad C3 mode.

## Testing Results

RAM cards have been tested on different combinations of CPC main boards and components including

- 3 CPC 464 main board types on 6 different CPC464 machines
- 1 CPC 6128 main board type on 2 different CPC6128 machines
- Type 0,1 and 2 CRTCs
Z80 CPUs from Zilog, Mostek, NEC, and SGS-Thomson as well as the UA880 CPU used in the KC Compact

•

- both 40010 and 40007 gate arrays

Cards have been tested using different expansion boards shared with other peripherals

- Mother X4, Revaldinho Backplane, LambdaBoard expansions cards

- SixROM, FourROM, X-MEM, ROMBO REDUX ROM boards
- DDI-3 SD Card and DDI-1 Disk interfaces
- M4 multi-function card

A standard test suite has been used made up of

Memory test programs including Duke's 512kb test and Gerald's memory test ROM (for the full shadow mode) and others

•

- Application tests: DK'Tronics silicon disk and bank switching software
- Operating systems: FutureOS and CP/M Plus
- Demos: Phortem and Batman Forever[4]
- Games: including Zaptball, Prehistorik II, R-Type, Gryzor, Robocop and others

All tests have been run either using power from the CPC +5V edge connector pin or a 4.5V bench supply.

Selected tests have been swept across voltage from 4.35V to 5.5V.

Full Test results are visible on Google Sheets here (see the RC-5-Elephant Tab)

https://docs.google.com/spreadsheets/d/11wxhIDWy2wNmKSXZwBqjqQjMN2nNZDtILEvy6_GrM8I/edit?usp=sharing

Some additional basic compatibility testing has also been done with the following machines

- Amstrad 664
- Amstrad 464 cost-down version [ASIC]
- Amstrad 464 Plus
- Amstrad 6128 Plus
- KC Compact

## Footnotes

[1] Compatible expansion boards include ToTO's Mother X3, Revaldinho CPC Backplane, LambdaMikel LambdaBoard.
[2] When using shadow mode the card size is effectively reduced to 448KBytes
[3] Shadow mode cannot presently be used when deplying pairs of RAM cards or in conjunction with other RAM cards.
[4] The Batman Forever demo does not run on CTRC Type 2 machines

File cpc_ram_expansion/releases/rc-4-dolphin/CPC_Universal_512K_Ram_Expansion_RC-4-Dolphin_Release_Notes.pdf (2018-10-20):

## Summary

This is a universal 512K RAM expansion card for all Amstrad CPC models.

The board has an 'M4' connector so requires a suitable motherboard or adapter to mount on the CPC.

On the 6128 and later computers the board provides a full 512K RAM expansion following the DK'Tronics/Amstrad specification.

On 464 and 664 computers the board will provide either
a full 512K RAM expansion with the same limitations on mode C3 which the DK'Tronics and other available '464 RAM cards have (e.g. X-MEM, Zaxon), or

•

a slightly smaller 448K expansion with full CPC6128 compatibility in mode C3, where one 64K bank is given up and used to shadow internal RAM.

•

DIP switches can be used to configure the device so that the new RAM is mapped either to IO port &7Fxx or &7Exx. Thus two cards can be used together to create a 1MB expansion, or the card can be used either with an X-MEM or Y-MEM to achieve the same 1MB expansion together with 512KB of Flash ROM from the X/Y-MEM card.

## Release Notes

RC-4-Dolphin is the first release candidate for beta testing.

The main change in this release candidate is the additional decoding to allow the 512K RAM to appear either at IO Address 7Fxx or 7Exx. This allows two RAM cards to work together to provide a 1MB expansion. It also make the card compatible with the existing X-MEM and Y-MEM cards from ToTO. Selection of IO Port address is controlled by the DIP switches and this has necessitated recoding all the combinations.

- DIP Switch settings are totally different in this build compared with previous releases. DIP switches 3 and 4 to take effect you need to power cycle the CPC. These switches are read and latched only on startup.

The new DIP settings and effects are listed below

## CPC Universal 512K Ram Expansion RC-4-Dolphin Release Notes

Tuesday, 16 October 2018 23:17

Config | DIP 1234 | 464/Z80 overdrive | Port | Shadow/ Bank | Compatibility X-MEM | Y-MEM | RAM | C3 Mode
0 | 0000 | OFF | 7Fxx | None/x | No | Yes | 512KB | AMS
1 | 0001 | OFF | 7Fxx | None/x | No | Yes | 512KB | AMS
2 | 0010 | OFF | 7Exx | None/x | Yes | No | 512KB | AMS
3 | 0011 | OFF | 7Exx | None/x | Yes | No | 512KB | AMS
4 | 0100 | ON | 7Fxx | None/x | No | Yes | 512KB | DK'T
5 | 0101 | ON | 7Fxx | None/x | No | Yes | 512KB | DK'T
6 | 0110 | ON | 7Exx | None/x | Yes | No | 512KB | DK'T
7 | 0111 | ON | 7Exx | None/x | Yes | No | 512KB | DK'T
8 | 1000 | ON | 7Fxx | Partial/lo | No | No | 448KB | AMS
9 | 1001 | ON | 7Fxx | Partial/hi | No | No | 448KB | AMS
10 | 1010 | ON | 7Fxx | Partial/lo | No | No | 448KB | AMS
11 | 1011 | ON | 7Fxx | Partial/hi | No | No | 448KB | AMS
12 | 1100 | ON | 7Fxx | Full/lo | No | No | 448KB | AMS
13 | 1101 | ON | 7Fxx | Full/hi | No | No | 448KB | AMS
14 | 1110 | ON | 7Fxx | Full/lo | No | No | 448KB | AMS
15 | 1111 | ON | 7Fxx | Full/hi | No | No | 448KB | AMS

In the table above, the compatibility columns show the settings which can be used with an X-MEM or Y-MEM to get a total of 1MB RAM expansion.

Recommended (and tested) configurations for the RAM card on its own are shown in bold in the table. E.g.
- 0 for CPC6128 providing standard 512KB expansion
- 4 for CPC464 providing standard 512KB expansion with DK'Tronics C3 mode
- 8 for CPC464 providing standard 448KB expansion with Amstrad C3 mode

Specification of other configurations is untested and may be changed in any future revisions.

## Using the RAM card in pairs or with X-MEM/Y-MEM

To use two RAM card in pairs to get a 1MB expansion, one card must be set up to map memory to IO Port &7Fxx and the other to IO Port &7E00.

When using a RAM card with X-MEM or Y-MEM the RAM card needs to have DIP switches set so that the memory IO port don't clash.
- X-MEM maps memory to IO port &7Fxx so set the RAM card DIP to select &7Exx
- Y-MEM maps memory to IO port &7exx so set the RAM card DIP to select &7Fxx

Shadow memory modes are not supported when using cards in pairs or with other RAM cards.

## Testing Results

Several cards have been tested on both CPC464s and CPC6128s

Full tests have been run at 4.5V, but some additional tests have been run in the voltage range 4.25V through 5.5V.

Full Test results are visible on Google Sheets here (see the RC-4-Dolphin Tab)

https://docs.google.com/spreadsheets/d/11wxhIDWy2wNmKSXZwBqjqQjMN2nNZDtILEvy6_GrM8I/edit?usp=sharing

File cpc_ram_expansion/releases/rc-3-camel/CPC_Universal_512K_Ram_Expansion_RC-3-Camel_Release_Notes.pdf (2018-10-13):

### Summary

This is a universal 512K RAM expansion card for all Amstrad CPC models.

The board has an 'M4' connector so requires a suitable motherboard or adapter to mount on the CPC.

On the 6128 and later computers the board provides a full 512K RAM expansion following the DK'Tronics/Amstrad specification.

On 464 and 664 computers the board will provide either
a full 512K RAM expansion with the same limitations on mode C3 which the DK'Tronics and other available '464 RAM cards have (e.g. X-MEM, Zaxon), or

•

a slightly smaller 448K expansion with full CPC6128 compatibility in mode C3, where one 64K banks is given up and used to shadow internal RAM.

•

### Release Notes

RC-3-Bulldog is the third release candidate for alpha testing.

This is a very minor change which changes adds a resynchronizer for the reset signal, changes FF resets from asynchronous to synchronous, reverts to prioritizing area over speed for synthesis, and fixes a number of outdated comments in the verilog code.

The DIP Switches work identically to the settings in RC-2-Bulldog

DIP | Function
1 | ON selects 464 mode which overdrives RD_B and ADR15 as required, OFF selects 6128/Plus mode
2 | turns on shadow memory

### CPC Universal 512K Ram Expansion RC-3-Camel Release Notes

Saturday, 13 October 2018 17:38

3 | selects partial shadow memory for mode3 only (OFF), or full shadow memory (ON) using SRAM instead of CPC base RAM for all addresses.
4 | selects shadow memory bank as low bank 3 (OFF) or high bank 7 (ON).

When setting DIP4 be careful because the DK'Tronics Silicon Disk software does not do a good check of the memory available. SDISC will declare banks 4-7 available for the disk even if DIP4 is set ON which effectively means that bank7 is not available.

NB - for DIP switches 3 and 4 to take effect you need to power cycle the CPC. These switches are read and latched only on startup.

Recommended DIP settings in this release candidate are

Config. | DIP1 | DIP2 | DIP3 | DIP4 | Application | Comment
1 | OFF | OFF | OFF | OFF | 6128 or Plus computers | Disable overdrive and shadow memory and provide a full 512K expansion
2 | ON | ON | OFF | OFF | 464 or 664 computer using DK'Tronics silicon disk | Provides a 448KB extension which can be used as a 256K silicon disk + a 192K RAM expansion
3 | ON | ON | OFF | ON | 464 or 664 computer not using DK'T silicon disk | Provides a 448KB extension
4 | ON | ON | ON | OFF | 464 or 664 computer using DK'Tronics silicon disk | Provides a 448KB extension which can be used as a 256K silicon disk + a 192K RAM expansion using full shadow memory so that all memory reads always come from the SRAM
5 | ON | ON | ON | ON | 464 or 664

Provides a 448KB

5 | ON | ON | ON | ON | 464 or 664 computer not using DK'T silicon disk | Provides a 448KB extension, using full shadow memory so that all memory reads always come from the SRAM
6 | ON | OFF | OFF | OFF | 464 or 664 computers | This is the true DK'Tronics mode which does not fully support mode C3 in the same way as on the 6128, but does provide a full 512K expansion and for most purposes is sufficient - see the results table below.

Other configurations are possible, but not currently tested or recommended.

Note when running a 464 in configurations 4 or 5 (full shadow memory) the base RAM of the CPC is only ever used for video data. Thus this card can potentially revive dead CPCs which have faulty base RAM with the only proviso that any faults in video RAM will result in visible pixel corruption on screen. Full shadow mode has been tested with Gerald's RamTest ROM - see below.

### Testing Results

Several cards have been tested now using 3 different CPCs: 1x CPC464 and 2xCPC6128s

Full tests have been run at 4.5V, but some additional tests have been run in the voltage range 4.25V through 5.5V.

Full Test results are visible on Google Sheets here (see the RC-3-Camel Tab)

https://docs.google.com/spreadsheets/d/11wxhIDWy2wNmKSXZwBqjqQjMN2nNZDtILEvy6_GrM8I/edit?usp=sharing

### Power Consumption

See RC-2-Bulldog release notes for last power measurements

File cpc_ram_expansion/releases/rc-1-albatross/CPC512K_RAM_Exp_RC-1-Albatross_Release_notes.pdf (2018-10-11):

### Summary

This is a universal 512K RAM expansion card for all Amstrad CPC models.

The board has an 'M4' connector so requires a suitable motherboard or adapter to mount on the CPC.

On the 6128 and later computers the board provides a full 512K RAM expansion following the DK'Tronics/Amstrad specification.

On 464 and 664 computers the board will provide either a full 512K RAM expansion but with the same limitations on mode C3 which the DK'Tronics cards have, or a small 448K expansion which removes those limitations. In the latter case one 64K bank is given up and used to shadow internal RAM

Current status is that the card is fully working for the 6128/Plus computers, but the 464/664 modes are still in development. Release notes follow with more detail.

### Release Notes

RC-1-Albatross is the first release candidate for alpha testing.

In this release the ability to run in overdrive mode without shadow memory is disabled.

In fact the board can happily run in overdrive mode only (like all other cards) but when the code to enable both options is included a timing problem means that running Future OS in shadow mode has a strong voltage dependency: unless Vdd can be kept above 5V the Future OS pointer is not clearly visible. The pointer gets progressively less visible (white pixels missing) as the voltage decreases. Adding an additional term into the A15 overdriving code resolves this so that FutureOS runs fine with Vdd down as far as 4.5V but this term breaks the overdrive-without-shadow memory operation.

So, currently the DIP Switches work as follows

## CPC 512K Ram Expansion RC-1-Albatross Release Notes

Saturday, 6 October 2018 19:07

DIP | Function
1 | selects 464 mode which overdrives RD_B and ADR15 as required AND turns on shadow memory
2 | turns on shadow memory if not already turned on by DIP1 above
3 | selects partial shadow memory for mode3 only (OFF) or full shadow memory (ON) using SRAM instead of CPC base RAM for all addresses.
4 | selects shadow memory bank as low bank 3 (OFF) or high bank 7 (ON).

When setting DIP4 be careful because the DK'Tronics Silicon Disk software does not do a good check of the memory available. SDISC will declare banks 4-7 available for the disk even if DIP4 is set ON which effectively means that bank7 is not available.

Recommended DIP settings in this release candidate are

Configuration | DIP1 | DIP2 | DIP3 | DIP4 | Application | Comment
1 | OFF | OFF | OFF | OFF | 6128 or Plus computers | Disable overdrive and shadow memory and provide a full 512K expansion for these machines
2 | ON | DON’T CARE | OFF | OFF | 464 or 664 computer using DK'Tronics silicon disk | Provides a 448KB extension which can be used as a 256K silicon disk + a 192K RAM expansion
3 | ON | DON'T CARE | OFF | ON | 464 or 664 computer not using DK'T silicon | Provides a 448KB extension

disk

Other configurations are possible, but not currently recommended.

### Testing Results

Test conditions
- 6128 BASIC ROM + Firmware installed on SixROM card in 464 during testing RAM Card powered by bench PSU @ 4.8V (unless indicated otherwise) independently of CPC power

•

| CPC464 | CPC6128 | CPC6128 | Notes
Machine ID | Revaldinho 46xxxx K32-5x | Revaldinho 133977 K32-57 | RobC 115286 K32-56
Board Connection | Via DDI-3 on Revaldinho Backplane | Revaldinho Backplane | Revaldinho Backplane
CRTC Type | 2 | 2 | 1 | Note different CRTC in 2nd 6128
DIP SWITCHES | Config. 3 | Config 1. | Config 1.
DIP1: Overdrive | ON | OFF | OFF | Select ON only for 464/664 computers
DIP2: Shadow Mode | X | OFF | OFF | Don't care if DIP1 is ON -option is disabled in that case by the CPC464 _SHADOW_ONLY_OPERATION conditional clause in the Verilog
DIP3: Full Shadow Mode | OFF | OFF | OFF
DIP4: Shadow Bank High (ON) or Low (OFF) | ON | OFF | OFF

RAM Test

RAM Test Programs

Ramtest.bas | PASS | PASS | PASS | Quick test to identify available blocks and check DIP settings
TEST.BIN | PASS | PASS | PASS | Full RAM test
RAMTEST.BIN | PASS | PASS | PASS | Alternative test (BCPL) for modes 4-7 only
RAM512KB.BIN (Duke) | PASS | PASS | PASS | Correctly shows 448KB on 464 with shadow mode on and passing on all banks

Applications
FutureOS GUI | PASS | PASS | todo
CP/M Plus | PASS | PASS | todo | Boot to OS, run basic utilities etc
CP/M Plus Turbo Pascal | PASS | todo | todo | Load, edit, compile, run Hello World program
DK'Tronics Silicon Disk | PASS | PASS | PASS
DK'Tronics Bank Manager | PASS | PASS | todo

Demos
Phortem | PASS | PASS | PASS
Batman Forever | NA | NA | PASS | Cannot run on CRTC Type 2

Games
Zaptball | PASS | NA | NA | Doesn't run from Gotek on drive B on CPC6128
R-Type | PASS | todo
Double Dragon | PASS | PASS | PASS | Loading screen corrupt, but game play and intermediate screens perfect. Same behaviour on the 464 and 6128, both with type 2 CRTC. Only the type 1 CRTC has clean

loading screens (blank blue screen)
Prehistorik II | PASS | todo
ChaseHQ | PASS | todo
Hard Drivin' | PASS | todo
P-47 | FAIL | FAIL ! | FAIL | On 464 loading screen ok, game screen blank - may not be a RAM issue as on 6128 game starts but screen is totally corrupt. All machines fail in slightly different ways, ie not even the 2 6128's match.
Robocop | PASS | NA | NA | Doesn't run from Gotek on drive B on CPC6128
Gryzor | PASS | todo | PASS
Alien8 | NA | NA | PASS | Cannot run on CRTC Type 2

### Power Consumption

Supply Voltage | Current
4.5V | 90mA
4.75V | 100mA
5.0V | 115mA
5.25V | 130mA

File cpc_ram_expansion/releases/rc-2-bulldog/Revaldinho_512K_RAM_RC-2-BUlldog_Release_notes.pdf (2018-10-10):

### Summary

This is a universal 512K RAM expansion card for all Amstrad CPC models.

The board has an 'M4' connector so requires a suitable motherboard or adapter to mount on the CPC.

On the 6128 and later computers the board provides a full 512K RAM expansion following the DK'Tronics/Amstrad specification.

On 464 and 664 computers the board will provide either
- a full 512K RAM expansion with the same limitations on mode C3 which the DK'Tronics and other available '464 RAM cards have (e.g. X-MEM, Zaxon), or
- a slightly smaller 448K expansion with full CPC6128 compatibility in mode C3, where one 64K banks is given up and used to shadow internal RAM.

Current status is that the card is fully working for the 6128/Plus computers, but the 464/664 modes are still in development. Release notes follow with more detail.

### Release Notes

RC-2-Bulldog is the second release candidate for alpha testing.

The ability to run in overdrive mode without shadow memory is restored - this was disabled in the previous release candidate.

The code has been improved to be able to backdrive ADR15 in mode 3 if required before the first rising clock edge in a valid mreq cycle. Previously this was being driven based on the value of a FF clocked by that edge and there was a race between the CPLD version of the clock and CPC clock. This showed up as a voltage dependency in FutureOS which meant that the cursor was only visible when the supply was ramped up above 5V. This issue is resolved in the new code and Future OS works down to around 4.25V as all other tests attempted at that voltage.

### CPC Universal 512K Ram Expansion RC-2-Bulldog Release Notes

Sunday, 7 October 2018 11:15

At the other end of the valid MREQ cycle the RD* overdriving, if required, has been extended to the next trailing clock edge after rising MREQ* after seeing slightly different behaviour between the original prototype card (always reliable) and a second card just made up for mode testing (very occasional base RAM fails in the TEST.bin memory test). With this fix both cards now appear to behave identically and correctly.

The DIP Switches work as follows

DIP | Function
1 | ON selects 464 mode which overdrives RD_B and ADR15 as required, OFF selects 6128/Plus mode
2 | turns on shadow memory
3 | selects partial shadow memory for mode3 only (OFF), or full shadow memory (ON) using SRAM instead of CPC base RAM for all addresses.
4 | selects shadow memory bank as low bank 3 (OFF) or high bank 7 (ON).

When setting DIP4 be careful because the DK'Tronics Silicon Disk software does not do a good check of the memory available. SDISC will declare banks 4-7 available for the disk even if DIP4 is set ON which effectively means that bank7 is not available.

NB - for DIP switches 3 and 4 to take effect you need to power cycle the CPC. These switches are read and latched only on startup.

Recommended DIP settings in this release candidate are

Config. | DIP1 | DIP2 | DIP3 | DIP4 | Application | Comment
1 | OFF | OFF | OFF | OFF | 6128 or Plus computers | Disable overdrive and shadow memory and provide a full 512K expansion
2 | ON | ON | OFF | OFF | 464 or 664 computer using DK'Tronics silicon disk | Provides a 448KB extension which can be used as a 256K silicon disk + a 192K RAM expansion

3 | ON | ON | OFF | ON | 464 or 664 computer not using DK'T silicon disk | Provides a 448KB extension
4 | ON | ON | ON | OFF | 464 or 664 computer using DK'Tronics silicon disk | Provides a 448KB extension which can be used as a 256K silicon disk + a 192K RAM expansion using full shadow memory so that all memory reads always come from the SRAM
5 | ON | ON | ON | ON | 464 or 664 computer not using DK'T silicon disk | Provides a 448KB extension, using full shadow memory so that all memory reads always come from the SRAM
6 | ON | OFF | OFF | OFF | 464 or 664 computers | This is the true DK'Tronics mode which does not fully support mode C3 in the same way as on the 6128, but does provide a full 512K expansion and for most purposes is sufficient - see the results table below.

Other configurations are possible, but not currently tested or recommended.

Note when running a 464 in configurations 4 or 5 (full shadow memory) the base RAM of the CPC is only ever used for video data. Thus this card can potentially revive dead CPCs which have faulty base RAM with the only proviso that any faults in video RAM will result in visible pixel corruption on screen. Full shadow mode has been tested with Gerald's RamTest ROM - see below.

### Testing Results

Several cards have been tested now using 3 different CPCs: 1x CPC464 and 2xCPC6128s

Full tests have been run at 4.8V, but some additional tests have been run in the voltage range 4.25V through 5.5V.

Full Test results are visible on Google Sheets here

https://docs.google.com/spreadsheets/d/11wxhIDWy2wNmKSXZwBqjqQjMN2nNZDtILEvy6_GrM8I/edit?usp=sharing

### Power Consumption

Supply Voltage | Current | Comment
4.25V | 70mA | Technically below the minimum operating voltage of the CPLD, but all tests tried at this voltage (see table above) have passed
4.5V | 85mA
4.75V | 95mA | Likely supply voltage if used on Mother X4 due to schottky diode drop
5.0V | 105mA | Nominal 5V to match CPC
5.25V | 120mA
5.5V | 145mA

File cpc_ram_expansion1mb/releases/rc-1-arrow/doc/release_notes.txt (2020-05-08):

RC-1-Arrow
==========

8th May 2020

Changes in this release
=======================

First full release of firmware and 1MB RAM Card, with all modes implemented and tested on a CPC464 and CPC6128.

Bugs and Known Issues
=====================

XC9572 Version provides all features as described in the manual.

XC9536 Version merges the two shadow modes into one due to space
constraints in the CPLD. All shadow mode selections will select
'full shadow' operation. 

For CPC 6128 and Plus Machines
------------------------------

 - None

For CPC 464/664
---------------

 - CP/M+ and Zaptball run only in DK'Tronics mode

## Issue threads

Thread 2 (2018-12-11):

464 RAM Card: KC-Compact unexpected behaviour & non functional shadow mode

revaldinho, 2018-12-11:
This is an enhancement request for the KC-Compact.

The documentation currently shows the 464 card to be compatible with the KC-Compact in overdrive mode only, providing a full 512KB DK'Tronics expansion. Shadow mode is not supported.

Rennert reports on compatibility testing with the Robotron KC-Compact

1. Card  is working in both overdrive (DIP=0100) and non-overdrive modes  (DIP=0000).
- Verified by Duke's RAM512KB.BIN test
- Reports DK'Tronics C3 video mode operation
- Notes that using FutureOS in C3 mode cursor trail differs when enabling overdriving

2. Card doesn't work with shadow mode enabled - KC-Compact fails to start.

Item 1 isn't a problem since the card is working well with both settings, but it is unexpected.

The KC-Compact is a clone of the CPC464 and it is expected that the overdrive mode would have to be used to write protect the base RAM when writing to expansion banks. Rennert's report indicated that the base RAM is write protected simply by asserting RAMDIS as in a 6128.

Item 2 is related. Currently shadow mode is designated as unsupported in the documentation, but again if the KC-Compact is a true clone then this mode should work. Possibly a CPLD code change might be able to improve compatibility here.

Actions:

Need to check the KC-Compact schematics to understand:

1. how the base RAM is write protected during external RAM accesses
2. why shadow mode (A15 overdriving) doesn't work and whether a CPLD change might also allow the card to support this machine too.

Closed 2022-11-25.

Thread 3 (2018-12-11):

464 RAM Card: Odd pixels around Future OS Cursor/Malformed Cursor

revaldinho, 2018-12-11:
LambdaMikel reports two slight issues in shadow mode but only seen on one or two of his CPC464s.

Both CPC1 and CPC3 show a 'halo' of pixels around the FutureOS cursor:

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

Also seen on one CPC

> However, a few pixels are missing from [the cursor]! But it moves without problem.

This effect is different depending on which ROM cards are attached.

Diagnosis

Both of these may be PSU voltage supply dependent.

On the second item in particular I have seen with an earlier CPLD code that the FutureOS cursor might be faded, or have pixels missing when a single CPLD pin was used to overdrive ADR15 and the supply voltage dropped below around 4.8V. Ramping the supply voltage up improved the situation 'til the cursor was perfect indicating a timing issue with the overdrive. The solution in the final CPLD code is to use 2  CPLD pins ganged together to overdrive ADR15. In testing here on two CPC464s and with all varieties of Z80 (Zilog, SGS, NEC, UA880, MOSTEK) this was sufficient to guarantee correct operation down to around 4.35V instead.

Current action here is with LambdaMikel to try an external PSU and report whether increased voltage improves or resolves the situation.

revaldinho, 2018-12-14:
Update from LM

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

Confirms voltage dependency for this card which sounds like an earlier CPLD build where only one CPLD pin was used to drive ADR15. LM has checked and confirmed that his has the RC-5-Elephant release installed which should drive 2 pins and resolve this.

Still open...

revaldinho, 2020-02-02:
Closing this issue. This turned out to be a bad RAM chip on the original board. A Brilliance Semiconductor part was used originally, but when replaced with a nominally identical Alliance Semi one, the issue disappeared. In addition the new RC-6-Fighter firmware has improved timing and low voltage operation of the card in all modes.

Closed 2020-02-02.

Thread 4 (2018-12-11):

464 RAM Card: Unreliable operation of Card/Reading of DIP Switches

revaldinho, 2018-12-11:
LambdaMikel reports some issues with his (early build) RAM card where the cursor in Future OS disappears or acts like an erase. This occurs frequently but not always, can be fixed with a power cycle on some machines and others are dependent on the type of ROM card being used.

This issue is most likely due to the CPLD incorrectly reading the value of DIP3. On the original boards the SIL pull-up/down values were 47K/10K respectively. This was found to lead to unreliable reading of the DIP switches, possibly due to pull-ups internally on the CPLD pins when tristated . ( There are different versions of the datasheet for example and CPLDs have been obtained from several batches.)

This issue has already been address on the other board builds, either by adding a 10K SIL in parallel with the 47K pulldown (on the first few built cards) or by switching to much lower resistances for pull-up and pull-down at the expense of a few mA of static current.

Action is currently with LambdaMikel to add a 10K pullup on the back of his early card between DIP3 and ground and report if this resolves the issue.

revaldinho, 2020-02-02:
Closing this issue. No problems with the firmware RC-6-Fighter.

Closed 2020-02-02.

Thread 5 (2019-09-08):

CPC512K Ram ExpansionVersion 2.10 chip layout Please

revaldinho, 2019-09-08:
Hi Revaldinho

I am unable to find the Chip layout for CPC512K Ram ExpansionVersion 2.10

Can you send me a link please.

I found that I had a board under some cards in my workshop.
Started building and ? where do the chips go ?? and What are they ?

Thanks. Ray

revaldinho, 2019-09-08:
The V2.10 was an experiment and is a very slightly different design from the V2.01.

The difference is that when accessing the first expansion bank on a 6128 the V2.10 will use the built-in expansion in the CPC rather than RAM on the expansion card. On a 6128 actually it turns out that this makes no difference whatsoever in reliability or performance and both v2.01 and v2.10 work exactly the same as far as the end user is concerned.

The V2.01 then has a very small advantage in having one fewer IC and also being compatible with 464plus machines. So, the V2.01 is the one I recommend and the one shared on the SeeedFusion gallery site, but both have been built and fully tested on a couple of 6128s.

The mapping of components is slightly different between the two and not just with the extra U8 IC.These are the IC assignments for both

```
ID.     v2.01   v2.10
U0      HCT32   HCT10
U1      HCT02   HCT02
U2      HCT10   HCT27
U3      HCT00   HCT00
U4      HCT00   HCT00
U5      HCT00   HCT00
U6      HCT75   HCT75
U7      HCT174  HCT174
U8       -      HCT04
```

Closed 2019-09-08.

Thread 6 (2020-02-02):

DIP switches in v1.01 brd.

perencia, 2020-02-02:
I don't see the pads for the dip switchers on the 1.01 revision brd file...

revaldinho, 2020-02-02:
There are no DIP switches on the V1.01 revision of the RAM card. These were added on the V1.10 board. All the source for the V1.10 cards is present but I hadn't checked in the final Eagle board files (which are generated from an Eagle script which itself is generated by running the .v and .footer files through the netlister.py program).  I've added the zip file to the eagle releases area now.

perencia, 2020-02-02:
Thanks!

Closed 2020-02-20.

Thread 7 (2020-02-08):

74series_soic.lib used in Makefiles but not present in netlister repo.

perencia, 2020-02-08:

revaldinho, 2020-02-09:
None of the boards use the SOIC library so you can just delete the line from the Makefile. I've updated the netlister repo anyway to add 74series_soic.lib and an ic-sockets.lib (which has a 40 pin ZIF included).

Closed 2020-02-20.

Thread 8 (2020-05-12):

cpc_backplane_edge status

nicf82, 2020-05-12:
Hi

Is the status of the cpc_backplane_edge still correct, I'm taking it that the board has been designed and ordered but not tested?

Id like to order some and try building one but is now a good time to do it? Alternatively are there any distributors creating these yet?

Cheers
Nic

revaldinho, 2020-05-12:
Hi  Nic

Thanks for the mail and the reminder to update the docs.

In fact I got the boards only last week as they took a bit longer than normal to get back from China via Hong Kong. I built a couple of them up for testing and they work fine with my DDI-3 on the edge connector at the back and other slots full of various other project cards.  I’ll update the wiki shortly.

If you want to build one, you can get bare boards from Seeed directly, where a pack of 10 will cost about £15 including postage. This is the link to my [project gallery](https://www.seeedstudio.com/gallery-user.html?id=292951&user=richarde)

Use the same BOM from DigiKey as the other 4 slot card to identify the components you need and skip the one unlatched box connector.

I don’t think they’ve appeared from any eBay sellers yet, but if you want one already built up then I can provide one. If you PM me via the [cpcwiki forum](http://www.cpcwiki.eu/forum/) or email me directly via GitHub I'll send you a list of prices and payment details.

Rich.

Closed 2020-05-14.

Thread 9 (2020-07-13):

Six rom expansion eagle layout has no A14 line to roms

Amstrad-nutter, 2020-07-13:
Six rom expansion, The eagle layout v1.0 has no A14 line to roms and by virtue cannot access 32k roms just 16k which then log twice.

revaldinho, 2020-07-14:
This is covered in the documentation on the  [Wiki ](https://github.com/revaldinho/cpc_ram_expansion/wiki/CPC-Sixrom-Card)

The board is designed specifically for 28256 32K EEPROMs and 27128 16K EPROMs.  27256 32K EPROMS can be used but are limited to holding a single 16K image (stored twice but with only one of the DIP selected to prevent logging twice).

The 27256 and 28256 parts have the A14 and WE* (Vpp) pins swapped over, but of course it is easily possible to make the same change in the Eagle layout if you need to use 27256 parts instead. Alternatively adding a link will make the board compatible with both, but at the slight risk of accidentally overwriting EEPROM data if the user sets the link is incorrectly - something I chose to avoid with this release.

revaldinho, 2022-11-07:
The minor V1.10 revision of the board adds this feature now. The EPROM A14/EEPROM WE pin for each ROM is pulled up to  VDD by default, but by adding a jumper header on a two pin link the EPROM A14 pin will be driven by the CPLD. There are no changes to the CPLD firmware for the new board.

Closed 2022-11-07.

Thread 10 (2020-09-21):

Resistor pack array question

rapiqui, 2020-09-21:
Hi,

Could you please specify which is the value of the resistor pack array and the type (f.ex.: 9 pin + gnd).

I've been unable to figure it out.

Thanks!

revaldinho, 2020-09-21:
Thank you for your question.

Several of the projects in this repository use resistor packs. Which one are you building ?

R

rapiqui, 2020-09-21:
Hi @revaldinho,

Thanks for your swift reply.
It's the Amstrad Universal RAM Expansion 512k.

revaldinho, 2020-09-21:
For these two components, see the [PCB netlist](https://github.com/revaldinho/cpc_ram_expansion/blob/master/cpc_ram_expansion/pcb/cpc_ram512k_v110.v).

  **r6k8_sil5   sil0 (**
                    .common(VSS),
                    .p0(dip0),
                    .p1(dip1),
                    .p2(HIADR3),
                    .p3(HIADR4),
                    );
  **r3k3_sil5   sil1 (**
                    .common(VDD),
                    .p0(dip3_pu),
                    .p1(dip2_pu),
                    .p2(dip1_pu),
                    .p3(dip0_pu),
                    );

The first is a 6K8 pack and the second a 3K3. I didn't find any 5 pin arrays for the 6K8 when I ordered from Digi-Key so I used a 6 pin one and snipped off the last array leg. No problem finding 5 pin packs for the 3K3.

rapiqui, 2020-09-21:
Thanks,

Now is crystal clear ;)

revaldinho, 2020-09-21:
You're welcome. I'll close the issue now.

thanks

R

Closed 2020-09-21.

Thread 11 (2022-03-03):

Pin1/2 silkscreen is on the wrong end of the connector

SerErris, 2022-03-03:
Hi, I doublechecked now the design on the original here and it is the same as in my version I have (which is modified design by cpcstore.uk.co ...

The issue is .. if you looking on the board from top, the connector to CPC facing away from you, you can read the PIN numbering of the IDC connectors (1 and 2) on the left of the connector.

Actually Pin 1 and 2 are on the right side and the rows are exchanged.

Correct orientation would be as shown in the picture below. That is true for the edge connector version as well as for the V1.10 backplane
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

revaldinho, 2022-03-04:
The pin numbering shown on the silk screen for the box connectors is part of the library component data for that part. It does not correspond to the PIN numbers used on the edge connector of the CPC.

hanshuebner, 2022-05-11:
I was also confused by this, thank you for confirming.

Closed 2022-11-07.

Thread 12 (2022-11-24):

Idea for new project... simple DD1 Floppy controller......

pocoaust, 2022-11-24:
Hi mate,

Love your work, have built the backplane and ROM board.  No issues just an idea

Have you considered a simple DD1 Floppy interface replacement.  They are getting very hard to find. The rom could go on the ROM board, and a small addon board could carry the fdd controller and support logic on your bus expansion.

I have attached the DDI schematic, could you give me your thoughts on this.

Best Regards
Paul

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

revaldinho, 2022-11-25:
Thanks for your comments.

It's a good idea. I mean, there are plenty of SD card alternatives to the DDI-1 around for the 464/664 but I think that only Zaxon's DDI-3/4/5 boards provide physical drive interfaces.  I actually do have a DDI-3 and it works very well, also with a Gotek as Drive B on the expansion connector.

Deleting the ROM and control circuitry is definitely the thing to do. I would like to keep any board smaller than 80x100mm to fit the freeware- Eagle license (100x100mm is also the limit for the cheap proto-packs from Seed). This would probably fit without the ROM.

I'll think about it. I have a couple of other projects in progress at the moment, so it may take a while to get to this and although I don't really need one myself,  I agree that it would be worth making a clone more generally available.

pocoaust, 2022-11-25:
That's great.  I am just a novice teaching myself in retirement, but am
happy to pay for test boards and have plenty of 765 ic etc which I could
send you.  Anyway let me know if there is anything I can do on my side and
please keep me in the loop.

Thanks Paul in australia.
Take care...

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

pocoaust, 2022-11-25:
Just an after thought, 3.5" style connector so you could support gotek as
mentioned would be ideal.

Take care. Paul;-)

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

pocoaust, 2022-11-26:
Tried to send this to you but github said was 2 large.

Here is link....

https://www.grimware.org/lib/exe/fetch.php/documentations/hardware/amstrad.cpc/manuals/service.manual.ddi-1.fd-1.pdf

Let me know if You need anything else.

Take care
Paul

grafzahl12345, 2022-11-26:
>

Hi revald,
are you also still useing eagle and is there enough space in the cpld for a second adress select logic? So i'm intrested too, you can cut me in if you like.

revaldinho, 2022-11-27:
Yes, for these projects at least I'm still using the netlister.py/freeware Eagle PCB tools.

For a DDI-1 clone without a ROM and the associated decoding I don't think there will be any need for a CPLD.  It may be possible to reduce the chip count by refactoring what's left with the ROM logic gone, so I think that it should all fit the in the 80x100mm constraint without any need to go for a CPLD.

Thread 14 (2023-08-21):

BOM for Universal RAM cards

WacKEDmaN, 2023-08-21:
ive got a PCB for the 512kb card on the way..  i cant seem to find the BOM for it tho
could you please add it revaldinho

thanks

andymccall, 2024-07-24:
Did you ever manage to get a BOM?

I've got 10x1MB cards, and I can't work out what parts are needed.  I've been building a list here:

https://www.digikey.co.uk/en/mylists/list/1DLY86MQVF

WacKEDmaN, 2024-07-24:
nope no help from anyone in the amstrad community... SMH..

i managed to make my own list aswell... after looking at this file i managed to stumble across in the repository...
https://github.com/revaldinho/cpc_ram_expansion/blob/master/cpc_ram_expansion/pcb/cpc_ram512k_v110.v
it has a list of where every component connects to... but its also where i found the resistor values etc...
no idea why a list of components is not included with the RELEASE projects...

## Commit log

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2018-03-19 Revised PCB, more signals into/out of CPLD, CPLD netlist not in sync
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2018-03-19 Update CPLD RTL + UCF to match PCB pinout
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2018-03-30 Swap rows of 50W connector over; fatten signal wires; pin reallocation on CPLD (UCF+PCB in sync
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2018-03-30 Revert SRAM to 5V rail: ViH cannot exceed Vcc+0.3V
2018-03-30 remove kiCAD reference - 'free' Eagle ok for now ...
2018-04-05 Add first hack for 74 Series board and update PCB generating README
2018-04-05 Add first cut of 74 series PCB; layout test only/netlist unverified currently
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2018-04-07 Make separate autorouter.ctl settings for 74 series board
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2018-04-08 Add cpp into flow for conditional #ifdef etc
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2018-04-08 Update snaps after some manual power optimisation
2018-04-19 Improvements/simplifications to CPLD code - working on 1st proto board with mini soak test
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2018-04-20 Rework 74 series netlist to match CPLD ; update 74 PCB files
2018-04-20 Add OSHPark Board images ; small tweak for CONN0 position
2018-04-22 Add BASIC RAM test program ; minor placement change for 74 series board
2018-04-25 Fix CPC Connector pinout on CPLD boards to be MX4 compatible
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2018-04-27 revised CPLD and 74 gates code, validated in simulation and on prototype board
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2018-04-27 Add Eagle board release files
    [CPC_RAM512K_V1.00.brd]
2018-04-27 Add fixed connector for original CPLD board + new 74XX board
    [CPC_RAM512K_SN74_V2.00.brd, CPC_RAM512K_V1.01.brd]
2018-04-28 Manual tweaks to 74XX board, mainly power improvements
    [CPC_RAM512K_SN74_V2.00.brd]
2018-04-29 Add SN74 version release files
    [CPC_RAM512K_SN74_V2.00.brd]
2018-04-29 Update 74 Series board, add 1 more decap, rework PCB layout
2018-04-29 Minor reworking of lower left corner to improve SRAM ground connection
    [CPC_RAM512K_SN74_V2.00.brd]
2018-04-30 Add lowrom board and additional libraries in header
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2018-05-05 Add first cut of Teensy3.5 based ROMBoard
    [T35_ROMBOARD_V1.00.brd]
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2018-05-07 Updates to Teensy 3.5 ROM board
    [T35_ROMBOARD_V1.00.brd]
2018-05-07 Add CPC Backplane PCB files
    [CPC_BACKPLANE_V1.00.brd]
2018-05-07 Add missing FOURROM board release file
    [CPC_FOURROM_V1.00.brd]
2018-05-07 Minor trim of CPC_BACKPLANE Board size to fit Seeed 100x100mm limit
    [CPC_BACKPLANE_V1.00.brd]
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2018-05-20 Manual updates to board layout
    [CPC_RAM512K_SN74_v2.01.brd]
2018-05-20 Add zipped archive of board files for Seeed
2018-05-20 Update cpc_backplane PCB
    [CPC_BACKPLANE_V1.00.brd]
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2018-05-22 Working shadow RAM code with CPLD RAMboard - lose only 64K capacity
2018-05-27 Minor board updates for backplane and 74 series RAM exp ; update utils
    [CPC_BACKPLANE_V1.00.brd]
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2018-06-01 Add PCB and Seeed release files for V2.10 RAM board
    [CPC_RAM512K_SN74_v2.10.brd]
2018-06-01 Add one more decap, minor power changes
    [CPC_RAM512K_SN74_v2.10.brd]
2018-06-03 Revised footprint for Teensy3.5 and update pin allocations for ROM board
2018-06-03 Add cpc_sixrom files
    [CPC_SIXROM_v1.00.brd]
2018-06-03 Add updated T35 ROMBOARD with Teensy 3.5 footprint changes
    [T35_ROMBOARD_v1.10.brd]
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2018-06-03 Revise CPLD pinout to match PCB for CPC_SIXROM
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2018-06-13 Remove one level shifter IC & revise board
2018-06-14 Rework board to use a single PLCC84 CPLD
2018-06-14 Add SMD caps to CPC_6502 & board rework
2018-07-01 restore v2.01 RAM board PCB; updates to ROM/RAM CPLDs for XC9536 ; Misc README updates
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2018-08-03 Add Eagle release files for CPC_6502
    [CPC_6502_V1.00.brd]
2018-08-12 Add extra slot to backplane, simplify power options
2018-08-12 Add revised CPLD board for 464/6128 RAM expansion
2018-08-12 Add overdrive files to Master for use with hacked PCB only
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2018-09-08 First compatible CPLD code for the V1.10 CPC464 board
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2018-10-06 Restrict operation to 6128 or overdrive+shadow only, no volts dep in FOS, good performance/stability. Snapshot of files as RC-1
2018-10-07 Resolved FOS voltage dependency ! ADR15 to be driven _before_ first rising edge in MREQ* cycle
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2018-11-22 Correction - reset drives 0, then tristate and sample DIPs
2018-11-24 Re-enable A15_AUX to improve low voltage operation on MK3880 CPU
2018-11-29 Prune Z80 tube files - moved to separate repo
2019-01-01 Update 4 Slot version of backplane ready for mfg
2019-01-01 Add release files for backplane boards
    [CPC_BACKPLANE.brd, cpc_backplane_v1.10.brd]
2019-01-01 Add placement image for 4 slot backplane
    [cpc_backplane_v1.10.brd]
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2019-03-21 Update backplane releases area
    [cpc_backplane_v1.10.brd]
2019-10-03 Working version @4.25V running in DK'T and shadow modes!
2019-10-04 Timing tweaks improved FutureOS low voltage on CPC2
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2019-10-18 Add IC numbers on RAM board placement diagram
2020-04-05 Add new 4 slot backplane with edge connector
    [cpc_backplane_edge.brd]
2020-04-12 Add trial PCB + CPLD code for 1M RAM Card
2020-05-02 RAM1M: fix dip switch reading and allow shadow mode to be turned off for 464 to get full 1MB expansion
2020-05-06 RAM1MB: DK'tronics mode working, shadow mode working in FutureOS, full shadow implemented but needs testing
    [cpc_ram1m.brd]
2020-05-12 Add photo of 4 slot edge expansion board
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2020-07-13 RAM1M PLCC84: check in all files to build 1MB RAM/GPIO board and CPLD
2020-07-14 RAM1MB PLCC84: Add PCB release files
    [cpc_ram1mb_plcc84.brd]
2020-10-05 Add PCB layout for new 74 Series 1MB board
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2020-10-28 Add EightROM PCB files
    [cpc_ram1m_74_v1.00.brd, cpc_ram1mb_plcc84.brd]
2020-10-28 Reduce polygon wire width to create fenestrations for power
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2020-10-30 EightROM - Increase power spacing, tweak component placement
2020-11-03 Switch to 74HCT573 for data latching, minor IC/Cap movement
2020-11-04 Swap Bank DIP for link, correct lat_en polarity, pin reassignments and component movement to reduce via count/improve routing
2020-11-08 cpc_eightrom: Add PCB release files
    [cpc_eightrom.brd]
2020-11-09 CPC_EIGHTROM: add DRC check to end of footer, revise power width for next run
2020-11-28 Checkin misc PCB zip files
    [CPC_BACKPLANE_EDGE_V1.00.brd]
2020-12-30 Update README.md
    Add EightROM to list of projects, now that board is full built and tested.
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2022-10-03 Update target in 1Mb RAM board to PLCC84
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2022-10-04 Add busrq_b/busack_b to UCF and verilog (now connected in PCB) and remove clock gating latch
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2022-10-17 Releases: remove unused releases, move outdated releases to archive
    [CPC_6502_V1.00.brd, CPC_FOURROM_V1.00.brd, CPC_RAM512K_SN74_V2.00.brd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]
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
